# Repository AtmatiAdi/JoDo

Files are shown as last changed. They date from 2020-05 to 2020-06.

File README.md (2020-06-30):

# Opis projektu

Głównym celem projektu jest stworzenie Joystick'a na bazie mikrokontrolera STM32F103. Założeniem jest aby uniwersalnym urządzeniem można było sterować różnymi robotami przez moduł Bluetooth lub WIFI, oraz tradycyjnie obsługiwać komputer poprzez interfejs USB jako joystick lub jako mysz. Ma on posiadać niżej opisane funkcjonalności:

* Baterie do pracy bez zasilania przewodowego.
* Zintegrowaną ładowarkę i kontrolę napięcia baterii.
* Gałkę precyzyjną i  szereg przycisków do kontroli i sterowania.
* Akcelerometr do różnego rodzaju kontroli lub jako kolejna “gałka joysticka”.
* Interfejs USB umożliwiający podłączenie do komputera jako urządzenie HID jak i ładowanie samego urządzenia.
* Moduł Bluetooth, WIFI i radiowy umożliwiający implementację sterowania różnego rodzaju robotami.
 
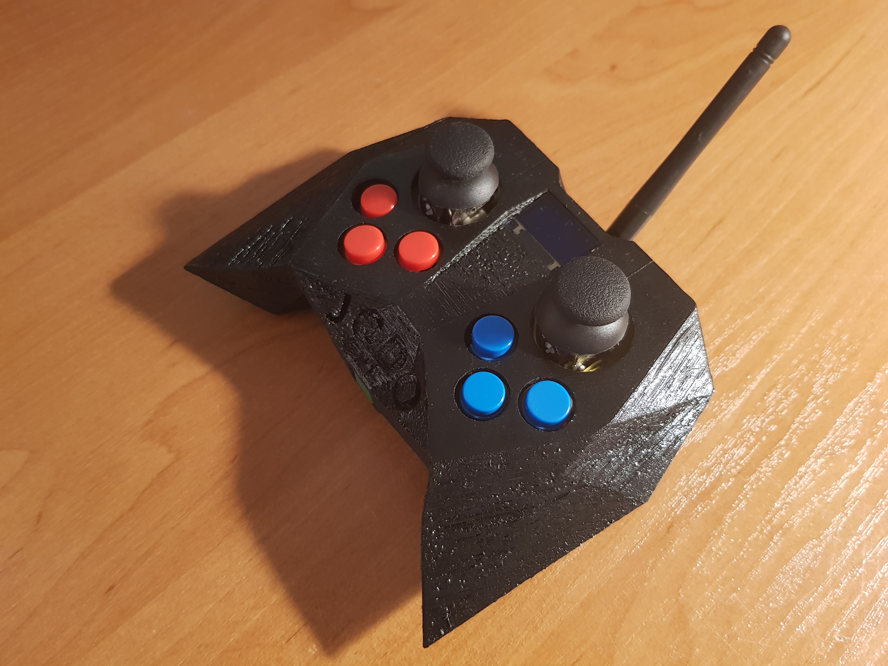
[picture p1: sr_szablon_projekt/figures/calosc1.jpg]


Mikrokontroler STM32F103 przez magistralę UART komunikować się będzie z modułem WIFI i modułem Bluetooth HC-05 aby umożliwić podłączenie i sterowanie innym urządzeniem. Moduł HC-05 jest programowalny (komendami AT można zmienić częstotliwość komunikacji i tryb pracy master/slave). Moduł komunikacji radiowej nRF24L01+ jest zasilany napięciem 1.9 - 3.6 V. Może pracować w trybie nadajnika i odbiornika. Wyświetlacz oled służy do wyświetlania informacji takich jak stan połączenia, informacje zwrotne z urządzenia, stan baterii itp. Przetwornica ma możliwość wyłączenia w przypadku rozładowania baterii, tym zarządza mikrokontroler. Głównym zadaniem będzie działanie jako joystick po podłączeniu do komputera przez USB. Moduł IMU służy jako kontroler tak jak sam joystick. Architektura systemu:

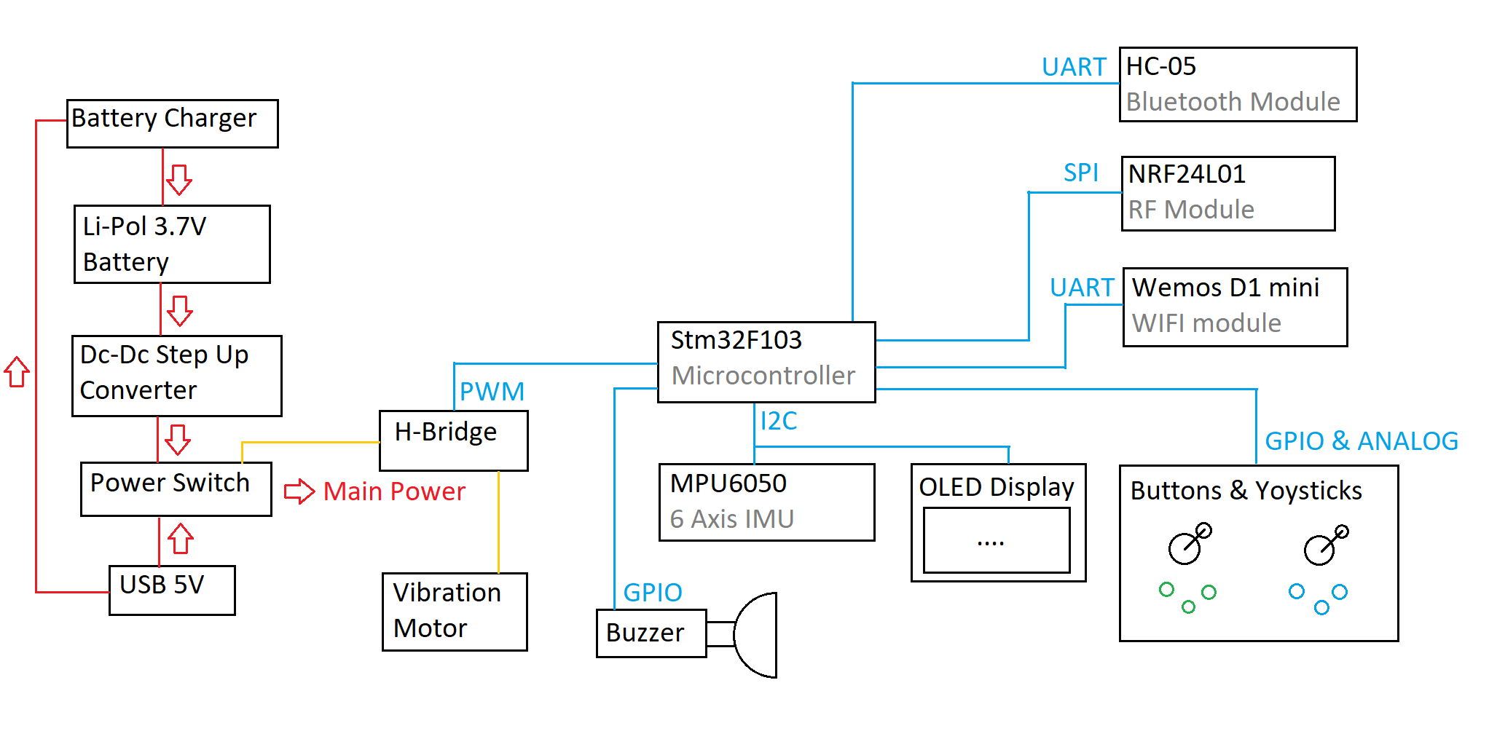
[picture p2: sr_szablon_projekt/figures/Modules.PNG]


# Opis działania programu

Uniwersalność urządzenia zapewniona jest poprzez możliwość wybierania trybów pracy. Tryb wybierany jest z menu  uruchamianego po włączeniu urządzenia. Do nawigacji po menu służą niebieskie przyciski - skrajne do zmiany opcji, a środkowy do zatwierdzenia. Podstawowym trybem jest praca jako gamepad, dodatkowo jednak na potrzeby projektu robota micromouse dodano tryb pracy jako mostek pomiędzy robotem a komputerem. W miarę potrzeb program można rozszerzyć o kolejne funkcje trybów z odpowiednio skonfigurowanymi peryferiami, w zależności od wymagań projektu. Program urządzenia podzielony jest na funkcje programów i na funkcje główne. Funkcje główne są odpowiedzialne za kontrolę urządzenia i inicjalizację modułów. Funkcje programów dzielą się na dwa typy: inicjalizacji i pętli, inicjalizacja wybranego programu sprowadza się do wywołania funkcji inicjalizujących moduły i~peryferia dostarczone przez funkcje główne, jest to umowny poziom abstrakcji. Funkcja petli programu jest rdzeniem programu, nie powinna ona byc nieskończoną pętlą, gdyz sama będzie wywoływana w takiej pętli, wraz z funkcją Update która odpowiedzialna jest za kontrolę baterii i zasilania. Program został zrealizowany w taki sposób, ponieważ nie można jednocześnie skonfigurować HID i interfejsu szeregowego, dalsze projekty mogły by powodowac inne konflikty. Wybór innego trybu pracy możliwy jest jedynie po zresetowaniu urządzenia.

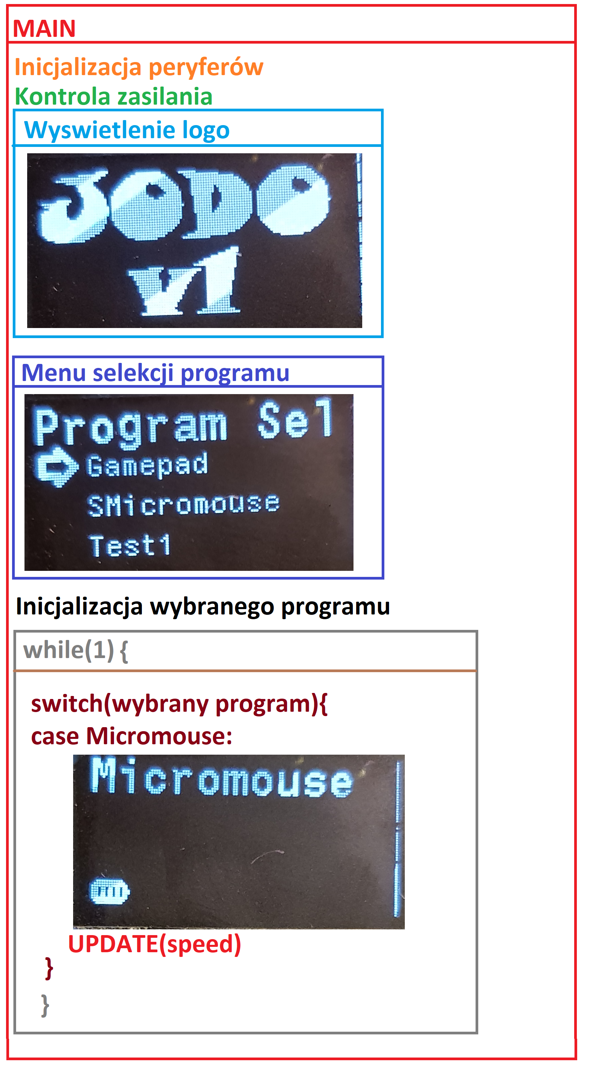
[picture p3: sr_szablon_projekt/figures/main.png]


# Linki 

https://youtu.be/tafsixhDsh8 - Prezentacja ukończenia projektu

https://www.overleaf.com/read/fwncyzqsmkhw - Raport końcowy

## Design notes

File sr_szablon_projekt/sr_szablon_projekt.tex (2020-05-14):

% !TeX encoding = UTF-8
% !TeX spellcheck = pl_PL

% $Id:$

%Author: Wojciech Domski
%Szablon do ząłożeń projektowych, raportu i dokumentacji z steorwników robotów
%Wersja v.1.0.0
%

%% Konfiguracja:
\newcommand{\kurs}{Sterowniki robot\'{o}w}
\newcommand{\formakursu}{Projekt}

%odkomentuj właściwy typ projektu, a pozostałe zostaw zakomentowane
\newcommand{\doctype}{Za\l{}o\.{z}enia projektowe} %etap I
%\newcommand{\doctype}{Raport} %etap II
%\newcommand{\doctype}{Dokumentacja} %etap III

%wpisz nazwę projektu
\newcommand{\projectname}{Joystick}

%wpisz akronim projektu
\newcommand{\acronim}{SteRoP\_2020\_J\_MKEZ\_1.pdf}

%wpisz Imię i nazwisko oraz numer albumu
\newcommand{\osobaA}{Mateusz \textsc{Kobak}, 241502}
%w przypadku projektu jednoosobowego usuń zawartość nowej komendy
\newcommand{\osobaB}{Ewa \textsc{Zi\k{e}tek}, 241479}

%wpisz termin w formie, jak poniżej dzień, parzystość, godzina
\newcommand{\termin}{ptTP11}

%wpisz imię i nazwisko prowadzącego
\newcommand{\prowadzacy}{dr in\.{z}. Wojciech \textsc{Domski}}

\documentclass[10pt, a4paper]{article}

\include{preambula}
	
\begin{document}

\def\tablename{Tabela}	%zmienienie nazwy tabel z Tablica na Tabela

\begin{titlepage}
	\begin{center}
		\textsc{\LARGE \formakursu}\\[1cm]		
		\textsc{\Large \kurs}\\[0.5cm]		
		\rule{\textwidth}{0.08cm}\\[0.4cm]
		{\huge \bfseries \doctype}\\[1cm]
		{\huge \bfseries \projectname}\\[0.5cm]
		{\huge \bfseries \acronim}\\[0.4cm]
		\rule{\textwidth}{0.08cm}\\[1cm]
		
		\begin{flushright} \large
		\emph{Skład grupy:}\\
		\osobaA\\
		\osobaB\\[0.4cm]
		
		\emph{Termin: }\termin\\[0.4cm]

		\emph{Prowadzący:} \\
		\prowadzacy \\
		
		\end{flushright}
		
		\vfill
		
		{\large \today}
	\end{center}	
\end{titlepage}

\newpage
\tableofcontents
\newpage

%Obecne we wszystkich dokumentach
\section{Opis projektu}
\label{sec:OpisProjektu}

Głównym celem projektu jest stworzenie Joystick na bazie mikrokontrolera STM32F103. Założeniem jest aby uniwersalnym urządzeniem można było sterować różnymi robotami przez interfejs Bluetooth lub WIFI. oraz tradycyjnie obsługiwać komputer poprzez interfejs USB jako joystick lub jako mysz, ma on posiadać niżej opisane funkcjonalności:
\begin{itemize}
	\item Baterie do pracy bez zasilania przewodowego.
	\item Zintegrowaną ładowarkę i kontrolę napięcia baterii.
	\item Gałkę precyzyjną i  szereg przycisków do kontroli i sterowania.
	\item Akcelerometr do różnego rodzaju kontroli czy będąc jako kolejna “gałka joysticka”.
	\item Interfejs USB umożliwiający podłączenie do komputera jako urządzenie HID jak i ładowanie samego urządzenia.
	\item Moduł Bluetooth i WIFI umożliwiający implementację sterowania różnego rodzaju robotami.
\end{itemize}
Krótki opis projektu czego będzie on dotyczył.

W przypadku, gdy projekt dotyczy systemu 
wielomodułowego należy dołączyć diagram, który będzie prezentował
architekturę systemu:

\begin{figure}[H]
	\centering
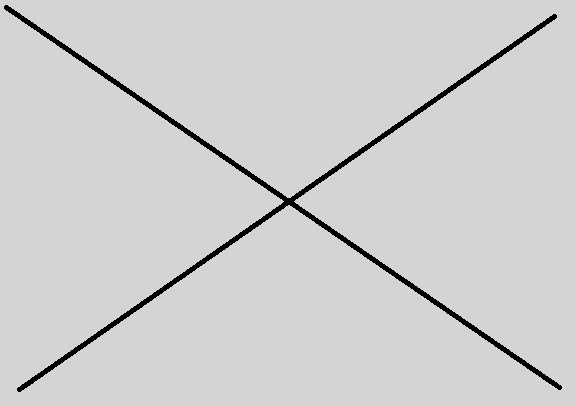
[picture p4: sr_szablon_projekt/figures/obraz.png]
	
	\caption{Architektura systemu}
	\label{fig:Architektura}
\end{figure}

%Obecne we wszystkich dokumentach
\section{Konfiguracja mikrokontrolera}

Tutaj powinna znaleźć się konfigurację poszczególnych peryferiów 
mikrokontrolera -- jeśli wykorzystywany jest np. ADC to należy 
podać jego konfigurację nie zapominając o DMA jeśli jest 
wykorzystywane. Proszę wzorować się na raporcie wygenerowanym 
z programu STM32CubeMx 
(plik PDF i TXT, Project -> Generate Report Ctrl+R). 
W pliku PDF jest to rozdział \textit{IPs} and \textit{Middleware Configuration}. 
Należy umieścić uproszczoną konfiguracje peryferiów w formie 
tabelek (najistotniejsze parametry + parametry zmienione, pogrubione).
Dodatkowo w pliku tekstowym (TXT) znajduje się konfiguracja pinów 
mikrokontrolera, którą również należy zamieścić w raporcie.

W przypadku, gdy projekt zakłada wykorzystanie większej liczby modułów
sekcję tą należy podzielić na odrębne podsekcje.

\begin{figure}[H]
	\centering
	
	\caption{Konfiguracja wyjść mikrokontrolera w programie STM32CubeMX}
	\label{fig:KonfiguracjaMikrokontrolera}
\end{figure}

\newpage
\begin{figure}[H]
	\centering
	
	\caption{Konfiguracja zegarów mikrokontrolera}
	\label{fig:KonfiguracjaZegara}
\end{figure}

%Obecne we wszystkich dokumentach
\subsection{Konfiguracja pinów}

\begin{table}[H]
	\centering
	\begin{tabular}{|l|l|l|l|}
		\hline
		Numer pinu	&	PIN & Tryb pracy & Funkcja/etykieta\\
		\hline
		2&	PC13 & ANTI\_TAMP	GPIO\_EXTI13	&B1 [Blue PushButton]\\
		3&	PC14 & OSC32\_IN*	RCC\_OSC32\_IN	&\\
		4&	PC15 & OSC32\_OUT*	RCC\_OSC32\_OUT	&\\
		5&	PH0&  OSC\_IN*	RCC\_OSC\_IN	&\\
		6&	PH1&  OSC\_OUT*&		RCC\_OSC\_OUT	\\
		16&	PA2&	USART2\_TX&	USART\_TX\\
		17&	PA3&	USART2\_RX&	USART\_RX\\
		21&	PA5&	GPIO\_Output&	LD2 [Green Led]\\
		29&	PB10&	I2C2\_SCL&	I2C\_SCL\\
		41&	PA8&	TIM1\_CH1&	PWM1\\
		46&	PA13*&	SYS\_JTMS-SWDIO&	TMS\\
		49&	PA14*&	SYS\_JTCK-SWCLK&	TCK\\
		55&	PB3*&	SYS\_JTDO-SWO&	SWO\\
		62&	PB9&	I2C2\_SDA&	I2C\_SCL\\
		\hline
	\end{tabular}
	\caption{Konfiguracja pinów mikrokontrolera}
	
\end{table}

%Obecne we wszystkich dokumentach
\subsection{USART}

Przykładowa konfiguracja peryferium interfejsu szeregowego.
Należy opisać do czego będzie wykorzystywany interfejs. 
Zmiany, które odbiegają od standardowych w programie CubeMX 
powinn być zaznaczone innym kolorem, jak to zostało pokazane 
w tabeli \ref{tab:USART}.

\begin{table}[H]
	\centering
	\begin{tabular}{|l|c|} \hline
		\textbf{Parametr} & Wartość \\
		\hline
		\hline  \textbf{Baud Rate}&11520  \\\hline
		\textbf{Word Length } & \textcolor{blue}{8 Bits (including parity)}\\\hline
		\textbf{Parity} &  None\\
		\hline
		\textbf{Stop Bits}& 1\\
		\hline
	\end{tabular}
	\caption{Konfiguracja peryferium USART}
	\label{tab:USART}
\end{table}

%Obecne w dokumencie do etapu II oraz III
%\section{Urządzenia zewnętrzne}

%Rozdział ten powinien zawierać opis i konfigurację wykorzystanych ukladów
%zewnętrznych, jak np. akcelerometr.

%Obecne w dokumencie do etapu II oraz III
%\subsection{Akcelerometr -- LSM303C}

%Akcelerometr został wykorzystany do ...

%Konfiguracja rejestrów czujnika została zaprezentowana w ...
%Wpisanie tych wartości do rejestrów urządzenia ... powoduje ...

%\begin{table}[H]
%	\centering
%	\begin{tabular}{|l|c|} \hline
%		\textbf{Rejestr} & Wartość \\
%		\hline
%		\hline
%		CTRL\_REG2 (0x21) & 0x12\\\hline
%		CTRL\_REG3 (0x22) & 0x13\\\hline
%	\end{tabular}
%	\caption{Konfiguracja peryferium USART}
%	\label{tab:Akcelerometr}
%\end{table}

%Obecne w dokumencie do etapu II oraz III
%\section{Projekt elektroniki}

%W przypadku, w którym projekt uwzględnia zastosowanie 
%dodatkowej elektroniki to wówczas jej opis powinien znaleźć się tutaj.
%Należy dołączyć schematy elektroniczne w formacie PDF 
%jako dodatek do dokumentu 
%za pomocą \textit{include}. Również w przypadku wytworzenia 
%płytek PCB powinny znaleźć się tutaj ich widoki za zachowaniem skali.
%Można również dołączyć zdjęcia 
%elektroniki po uprzednim skompresowaniu, aby wynikowy rozmiar 
%skompilowanego dokumentu nie był za duży.

%Obecne w dokumencie do etapu II oraz III
%\section{Konstrukcja mechaniczna}

%W przypadku, w którym projekt uwzględnia zastosowanie 
%mechaniki to wówczas jej opis powinien znaleźć się tutaj.
%Nie należy dzielić rysunków mechaniki na poszczególne rzuty, 
%wystarczy zamieścić wyrenderowane modele 3D.
%Można również dołączyć zdjęcia wykonanej 
%mechaniki po uprzednim skompresowaniu, aby wynikowy rozmiar 
%skompilowanego dokumentu nie był za duży.

%Obecne w dokumencie do etapu II oraz III
%\section{Opis działania programu}

%Należy zawrzeć tutaj opis działania programu.
%Mile widziany diagram prezentujący pracę programu.

%\begin{figure}[H]
%	\centering
%	\includegraphics[width=0.5\textwidth]{figures/obraz.png}
%	\caption{Diagram przepływu}
%	\label{fig:Program}
%\end{figure}

%Sekcję tą można podzielić na dodatkowe podsekcje w miarę potrzeb. 
%Do tego celu nalezy wykorzystać \textit{subsection}.

%W przypadku, dodania istotnego fragmentu kodu należy posłużyć się środowiskiem 
%lstlisting:

%\begin{lstlisting}[tabsize=2]
%int foo(void){
%return 2;
%}
%\end{lstlisting}

%Przykładowy wzór (\ref{eq:Wzor}):
%\begin{equation}
%\label{eq:Wzor}
%\Theta = \int_t^{t+dt} \omega \, dt.	
%\end{equation}

%Przykładowa pozycja bibliograficzna \cite{SR01} znajduje się 
%w pliku bibliografia.bib.

%Obecne w dokumencie do etapu I
\section{Harmonogram pracy}

Należy wstawić diagram Gantta oraz określić ścieżkę 
krytyczną. Ponadto zaznaczyć i opisać kamienie milowe.

\begin{figure}[H]
	\centering
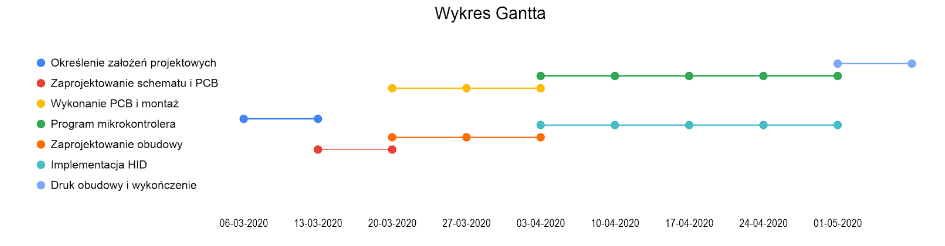
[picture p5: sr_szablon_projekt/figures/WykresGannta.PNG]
	
	\caption{Diagram Gantta}
	\label{fig:DiagramGantta}
\end{figure}

%Obecne w dokumencie do etapu I
\subsection{Podział pracy}

%\textbf{Każdy z członków grupy powinien w każdym etapie mieć wymienione od 2 do 4 zadań.}
%Przykładowa tabele podziału zadań dla etapu II 
%(Tab. \ref{tab:PodzialPracyEtap2}) oraz dla etapu III 
%(Tab. \ref{tab:PodzialPracyEtap3})
%zostały przedstawione poniżej. 
%Przy podziale prac nie uwzględniamy tworzenia dokumentacji projektu!

%Przykładowy podział prac dla projektu pod tytułem 
%"Automatyczny dyktafon rozmowy":

\begin{table}[H]
	\centering
	\begin{tabular}{|L{7cm}|L{0.8cm}||L{7cm}|L{0.8cm}|}
		\hline
		\hline
		\textbf{Mateusz Kobak} & 
		\% & 
		\textbf{Ewa Ziętek} & \%\\
		\hline
		\hline
			Dobranie odpowiednich komponentów	& &	
	 Dobranie odpowiednich komponentów &\\
		\hline
		Zaprojektowanie schematu i PCB & &
 &\\
		\hline
			 & &
		Wykonanie PCB i montaż & \\
		\hline
%		 & & &\\
%		\hline
	\end{tabular}
	\caption{Podział pracy -- Etap II}
	\label{tab:PodzialPracyEtap2}
\end{table}

\begin{table}[H]
	\centering
	\begin{tabular}{|L{7cm}|L{0.8cm}||L{7cm}|L{0.8cm}|}
		\hline
		\hline
		\textbf{Mateusz Kobak} & 
		\% & 
		\textbf{Ewa Ziętek} & \%\\
		\hline
		\hline
	Zaprojektowanie obudowy		& &	
		Program mikrokontrolera &\\
		\hline
	Implementacja HID  & &
		Druk obudowy i wykończenie &\\
		\hline

	\end{tabular}
	\caption{Podział pracy -- Etap III}
	\label{tab:PodzialPracyEtap3}
\end{table}

%Obecne w dokumencie do etapu II oraz III (jeśli coś zostało niezrealizowane)
%\section{Zadania niezrealizowane}

%Jeśli wszystkie zadania zostały realizowane to wówczas 
%ta sekcja powinna być usunięta w całości. W przeciwnym razie
%należy zawrzeć tutaj, jakie zadania zostały nie zrealizowane 
%oraz jaka była tego przyczyna.

%Obecne we wszystkich dokumentach
\section{Podsumowanie}

Urządzenie jest modułowe, więc ewentualna wymiana uszkodzonych elementów będzie łatwa. Drukowaną obudowę można łatwo powielić i wymienić. Budowa Joystick'a jest niedroga, tanim kosztem można zbudować ich więcej.

\newpage
\addcontentsline{toc}{section}{Bibilografia}
\bibliography{bibliografia}
\bibliographystyle{plabbrv}

\end{document}

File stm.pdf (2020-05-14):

## stm Project Configuration Report

# 1. Description

## 1.1. Project

Project Name | stm
Board Name | No information
Generated with: | STM32CubeMX 4.24.0
Date | 03/05/2020

## 1.2. MCU

MCU Series | STM32F1
MCU Line | STM32F103
MCU name | STM32F103CBTx
MCU Package | LQFP48
MCU Pin number | 48

# 2. Pinout Configuration

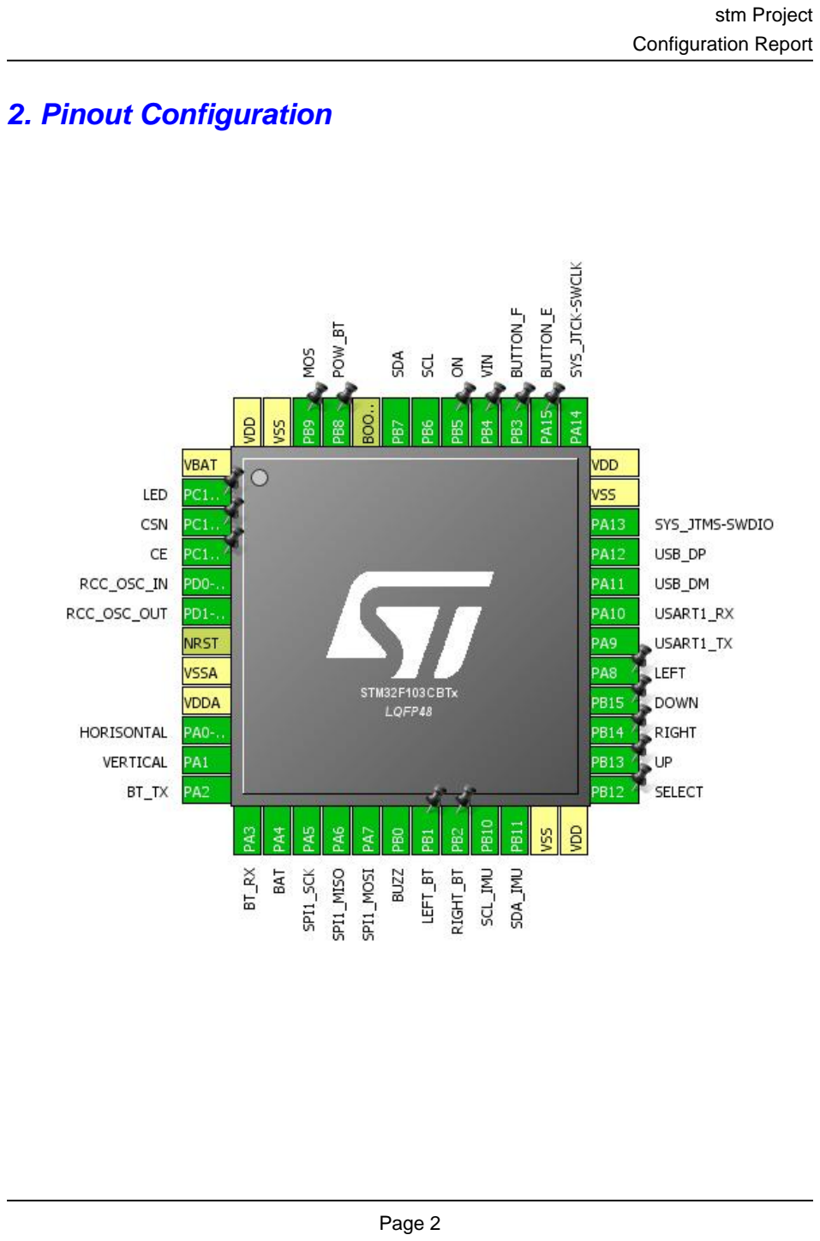
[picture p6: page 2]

# 3. Pins Configuration

Pin Number LQFP48 | Pin Name (function after reset) | Pin Type | Alternate Function(s) | Label
1 | VBAT | Power
2 | PC13-TAMPER-RTC * | I/O | GPIO_Output | LED
3 | PC14-OSC32_IN * | I/O | GPIO_Output | CSN
4 | PC15-OSC32_OUT * | I/O | GPIO_Output | CE
5 | PD0-OSC_IN | I/O | RCC_OSC_IN
6 | PD1-OSC_OUT | I/O | RCC_OSC_OUT
7 | NRST | Reset
8 | VSSA | Power
9 | VDDA | Power
10 | PA0-WKUP | I/O | ADC1_IN0 | HORISONTAL
11 | PA1 | I/O | ADC1_IN1 | VERTICAL
12 | PA2 | I/O | USART2_TX | BT_TX
13 | PA3 | I/O | USART2_RX | BT_RX
14 | PA4 | I/O | ADC1_IN4 | BAT
15 | PA5 | I/O | SPI1_SCK
16 | PA6 | I/O | SPI1_MISO
17 | PA7 | I/O | SPI1_MOSI
18 | PB0 | I/O | TIM3_CH3 | BUZZ
19 | PB1 * | I/O | GPIO_Input | LEFT_BT
20 | PB2 * | I/O | GPIO_Input | RIGHT_BT
21 | PB10 | I/O | I2C2_SCL | SCL_IMU
22 | PB11 | I/O | I2C2_SDA | SDA_IMU
23 | VSS | Power
24 | VDD | Power
25 | PB12 * | I/O | GPIO_Input | SELECT
26 | PB13 * | I/O | GPIO_Input | UP
27 | PB14 * | I/O | GPIO_Input | RIGHT
28 | PB15 * | I/O | GPIO_Input | DOWN
29 | PA8 * | I/O | GPIO_Input | LEFT
30 | PA9 | I/O | USART1_TX
31 | PA10 | I/O | USART1_RX
32 | PA11 | I/O | USB_DM
33 | PA12 | I/O | USB_DP
34 | PA13 | I/O | SYS_JTMS-SWDIO
35 | VSS | Power
36 | VDD | Power

Pin Number LQFP48 | Pin Name (function after reset) | Pin Type | Alternate Function(s) | Label
37 | PA14 | I/O | SYS_JTCK-SWCLK
38 | PA15 * | I/O | GPIO_Input | BUTTON_E
39 | PB3 * | I/O | GPIO_Input | BUTTON_F
40 | PB4 * | I/O | GPIO_Input | VIN
41 | PB5 * | I/O | GPIO_Output | ON
42 | PB6 | I/O | I2C1_SCL | SCL
43 | PB7 | I/O | I2C1_SDA | SDA
44 | BOOT0 | Boot
45 | PB8 * | I/O | GPIO_Input | POW_BT
46 | PB9 * | I/O | GPIO_Output | MOS
47 | VSS | Power
48 | VDD | Power

## * The pin is affected with an I/O function

# 4. Clock Tree Configuration

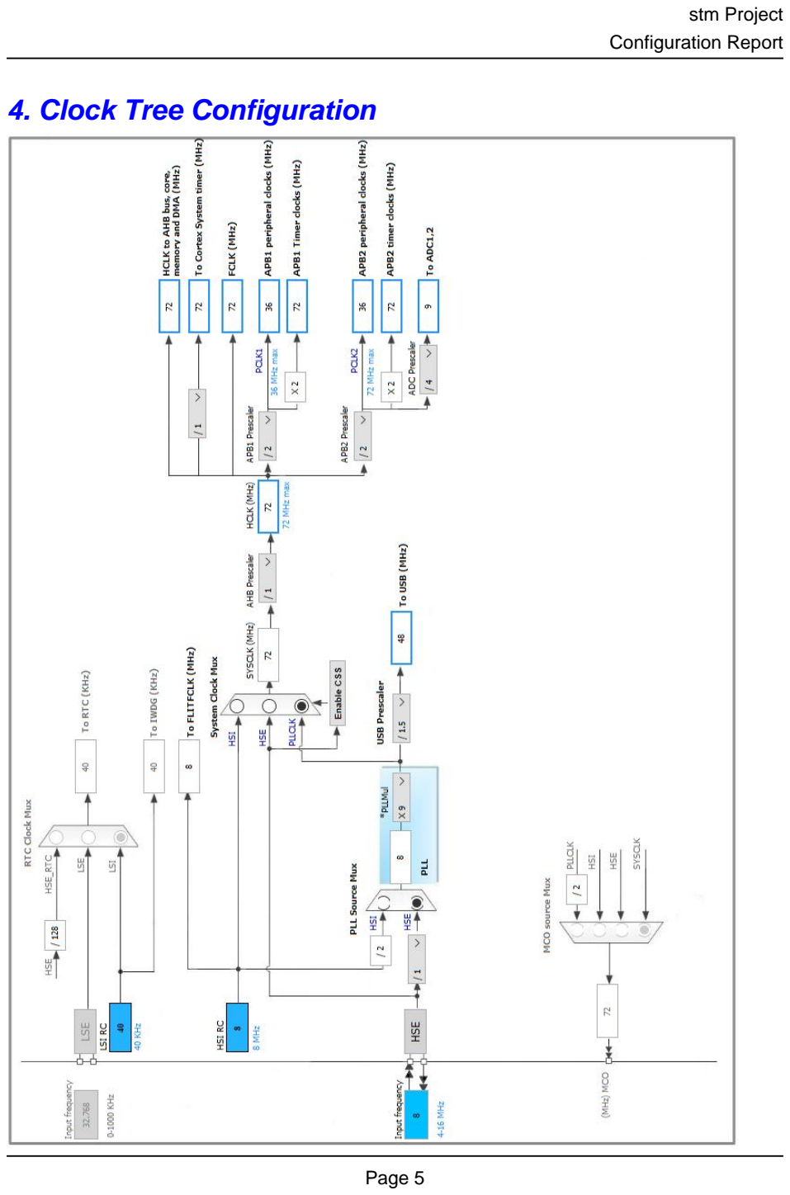
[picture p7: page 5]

# 5. IPs and Middleware Configuration

# 5.1. ADC1

## mode: IN0 mode: IN1 mode: IN4

## 5.1.1. Parameter Settings:

### ADCs_Common_Settings:

Mode | Independent mode

### ADC_Settings:

Data Alignment | Right alignment
Scan Conversion Mode | Disabled
Continuous Conversion Mode | Disabled
Discontinuous Conversion Mode | Disabled

### ADC_Regular_ConversionMode:

Enable Regular Conversions | Enable
Number Of Conversion | 1
External Trigger Conversion Source | Regular Conversion launched by software
Rank | 1
Channel | Channel 0
Sampling Time | 1.5 Cycles

### ADC_Injected_ConversionMode:

Number Of Conversions | 0

### WatchDog:

Enable Analog WatchDog Mode | false

# 5.2. I2C1

## I2C: I2C

## 5.2.1. Parameter Settings:

### Master Features:

I2C Speed Mode | Standard Mode
I2C Clock Speed (Hz) | 100000

### Slave Features:

Clock No Stretch Mode | Disabled
Primary Address Length selection | 7-bit
Dual Address Acknowledged | Disabled
Primary slave address | 0
General Call address detection | Disabled

# 5.3. I2C2

## I2C: I2C

## 5.3.1. Parameter Settings:

### Master Features:

I2C Speed Mode | Standard Mode
I2C Clock Speed (Hz) | 100000

### Slave Features:

Clock No Stretch Mode | Disabled
Primary Address Length selection | 7-bit
Dual Address Acknowledged | Disabled
Primary slave address | 0
General Call address detection | Disabled

# 5.4. RCC

## High Speed Clock (HSE): Crystal/Ceramic Resonator

## 5.4.1. Parameter Settings:

### System Parameters:

VDD voltage (V) | 3.3
Prefetch Buffer | Enabled
Flash Latency(WS) | 2 WS (3 CPU cycle)

### RCC Parameters:

HSI Calibration Value | 16
HSE Startup Timout Value (ms) | 100
LSE Startup Timout Value (ms) | 5000

# 5.5. SPI1

## Mode: Full-Duplex Master

## 5.5.1. Parameter Settings:

### Basic Parameters:

Frame Format | Motorola
Data Size | 8 Bits
First Bit | MSB First

### Clock Parameters:

Prescaler (for Baud Rate) | 2
Baud Rate | 18.0 MBits/s *
Clock Polarity (CPOL) | Low
Clock Phase (CPHA) | 1 Edge

### Advanced Parameters:

CRC Calculation | Disabled
NSS Signal Type | Software

# 5.6. SYS

## Debug: Serial Wire Timebase Source: SysTick

# 5.7. TIM3

## Channel3: PWM Generation CH3

## 5.7.1. Parameter Settings:

### Counter Settings:

Prescaler (PSC - 16 bits value) | 0
Counter Mode | Up
Counter Period (AutoReload Register - 16 bits value ) | 0
Internal Clock Division (CKD) | No Division
auto-reload preload | Disable

### Trigger Output (TRGO) Parameters:

Master/Slave Mode (MSM bit) | Disable (Trigger input effect not delayed)

Trigger Event Selection | Reset (UG bit from TIMx_EGR)

### PWM Generation Channel 3:

Mode | PWM mode 1
Pulse (16 bits value) | 0
Fast Mode | Disable
CH Polarity | High

# 5.8. USART1

## Mode: Asynchronous

## 5.8.1. Parameter Settings:

### Basic Parameters:

Baud Rate | 115200
Word Length | 8 Bits (including Parity)
Parity | None
Stop Bits | 1

### Advanced Parameters:

Data Direction | Receive and Transmit
Over Sampling | 16 Samples

# 5.9. USART2

## Mode: Asynchronous

## 5.9.1. Parameter Settings:

### Basic Parameters:

Baud Rate | 115200
Word Length | 8 Bits (including Parity)
Parity | None
Stop Bits | 1

### Advanced Parameters:

Data Direction | Receive and Transmit
Over Sampling | 16 Samples

# 5.10. USB

## mode: Device (FS)

## 5.10.1. Parameter Settings:

### Basic Parameters:

Speed | Full Speed 12MBit/s
Endpoint 0 Max Packet size | 8 Bytes

### Power Parameters:

Low Power | Disabled
Link Power Management | Disabled
Battery Charging | Disabled

# 5.11. USB_DEVICE

## Class For FS IP: Human Interface Device Class (HID)

## 5.11.1. Parameter Settings:

### Basic Parameters:

USBD_MAX_NUM_INTERFACES (Maximum number of supported interfaces) | 1
USBD_MAX_NUM_CONFIGURATION (Maximum number of supported configuration) | 1
USBD_MAX_STR_DESC_SIZ (Maximum size for the string descriptors) | 512
USBD_SUPPORT_USER_STRING (Enable user string descriptor) | Disabled
USBD_SELF_POWERED (Enabled self power) | Enabled
USBD_DEBUG_LEVEL (USBD Debug Level) | 0: No debug message

## 5.11.2. Device Descriptor:

### Device Descriptor:

VID (Vendor IDentifier) | 1155
LANGID_STRING (Language Identifier) | English(United States)
MANUFACTURER_STRING (Manufacturer Identifier) | STMicroelectronics

### Device Descriptor FS:

PID (Product IDentifier) | 22315
PRODUCT_STRING (Product Identifier) | STM32 Human interface
SERIALNUMBER_STRING (Serial number) | 00000000001A

CONFIGURATION_STRING (Configuration Identifier) | HID Config
INTERFACE_STRING (Interface Identifier) | HID Interface

### * User modified value

# 6. System Configuration

# 6.1. GPIO configuration

IP | Pin | Signal | GPIO mode | GPIO pull/up pull down

## Max Speed

## User Label

ADC1 | PA0-WKUP | ADC1_IN0 | Analog mode | n/a | n/a | HORISONTAL
| PA1 | ADC1_IN1 | Analog mode | n/a | n/a | VERTICAL
| PA4 | ADC1_IN4 | Analog mode | n/a | n/a | BAT
I2C1 | PB6 | I2C1_SCL | Alternate Function Open Drain | n/a | High * | SCL
| PB7 | I2C1_SDA | Alternate Function Open Drain | n/a | High * | SDA
I2C2 | PB10 | I2C2_SCL | Alternate Function Open Drain | n/a | High * | SCL_IMU
| PB11 | I2C2_SDA | Alternate Function Open Drain | n/a | High * | SDA_IMU
RCC | PD0- OSC_IN | RCC_OSC_IN | n/a | n/a | n/a
| PD1- OSC_OUT | RCC_OSC_OUT | n/a | n/a | n/a
SPI1 | PA5 | SPI1_SCK | Alternate Function Push Pull | n/a | High *
| PA6 | SPI1_MISO | Input mode | No pull-up and no pull-down | n/a
| PA7 | SPI1_MOSI | Alternate Function Push Pull | n/a | High *
SYS | PA13 | SYS_JTMS- SWDIO | n/a | n/a | n/a
| PA14 | SYS_JTCK- SWCLK | n/a | n/a | n/a
TIM3 | PB0 | TIM3_CH3 | Alternate Function Push Pull | n/a | Low | BUZZ
USART1 | PA9 | USART1_TX | Alternate Function Push Pull | n/a | High *
| PA10 | USART1_RX | Input mode | No pull-up and no pull-down | n/a
USART2 | PA2 | USART2_TX | Alternate Function Push Pull | n/a | High * | BT_TX
| PA3 | USART2_RX | Input mode | No pull-up and no pull-down | n/a | BT_RX
USB | PA11 | USB_DM | n/a | n/a | n/a
| PA12 | USB_DP | n/a | n/a | n/a
GPIO | PC13- TAMPER- RTC | GPIO_Output | Output Push Pull | n/a | Low | LED

PC14-
OSC32_IN
| GPIO_Output | Output Push Pull | n/a | Low | CSN
PC15- | GPIO_Output | Output Push Pull | n/a | Low | CE

IP | Pin | Signal | GPIO mode | GPIO pull/up pull down | Max Speed | User Label
| OSC32_OU T
| PB1 | GPIO_Input | Input mode | No pull-up and no pull-down | n/a | LEFT_BT
| PB2 | GPIO_Input | Input mode | No pull-up and no pull-down | n/a | RIGHT_BT
| PB12 | GPIO_Input | Input mode | No pull-up and no pull-down | n/a | SELECT
| PB13 | GPIO_Input | Input mode | No pull-up and no pull-down | n/a | UP
| PB14 | GPIO_Input | Input mode | No pull-up and no pull-down | n/a | RIGHT
| PB15 | GPIO_Input | Input mode | No pull-up and no pull-down | n/a | DOWN
| PA8 | GPIO_Input | Input mode | No pull-up and no pull-down | n/a | LEFT
| PA15 | GPIO_Input | Input mode | No pull-up and no pull-down | n/a | BUTTON_E
| PB3 | GPIO_Input | Input mode | No pull-up and no pull-down | n/a | BUTTON_F
| PB4 | GPIO_Input | Input mode | No pull-up and no pull-down | n/a | VIN
| PB5 | GPIO_Output | Output Push Pull | n/a | Low | ON
| PB8 | GPIO_Input | Input mode | No pull-up and no pull-down | n/a | POW_BT
| PB9 | GPIO_Output | Output Push Pull | n/a | Low | MOS

# 6.2. DMA configuration

## nothing configured in DMA service

# 6.3. NVIC configuration

Interrupt Table | Enable | Preenmption Priority | SubPriority
Non maskable interrupt | true | 0 | 0
Hard fault interrupt | true | 0 | 0
Memory management fault | true | 0 | 0
Prefetch fault, memory access fault | true | 0 | 0
Undefined instruction or illegal state | true | 0 | 0
System service call via SWI instruction | true | 0 | 0
Debug monitor | true | 0 | 0
Pendable request for system service | true | 0 | 0
System tick timer | true | 0 | 0
USB low priority or CAN RX0 interrupts | true | 0 | 0
PVD interrupt through EXTI line 16 | unused
Flash global interrupt | unused
RCC global interrupt | unused
ADC1 and ADC2 global interrupts | unused
USB high priority or CAN TX interrupts | unused
TIM3 global interrupt | unused
I2C1 event interrupt | unused
I2C1 error interrupt | unused
I2C2 event interrupt | unused
I2C2 error interrupt | unused
SPI1 global interrupt | unused
USART1 global interrupt | unused
USART2 global interrupt | unused

### * User modified value

# 7. Power Consumption Calculator report

### 7.1. Microcontroller Selection

Series | STM32F1
Line | STM32F103
MCU | STM32F103CBTx
Datasheet | 13587_Rev17

### 7.2. Parameter Selection

Temperature | 25
Vdd | 3.3

# 8. Software Pack Report

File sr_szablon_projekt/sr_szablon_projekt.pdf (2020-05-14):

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

## 1 Opis projektu

Gªównym celem projektu jest stworzenie Joystick na bazie mikrokontrolera STM32F103. Zaªo»eniem jest aby uniwersalnym urz¡dzeniem mo»na byªo sterowa¢ ró»nymi robotami przez interfejs Bluetooth lub WIFI. oraz tradycyjnie obsªugiwa¢ komputer poprzez interfejs USB jako joystick lub jako mysz, ma on posiada¢ ni»ej opisane funkcjonalno±ci:

| Baterie do pracy bez zasilania przewodowego.
| Zintegrowan¡ ªadowark¦ i kontrol¦ napi¦cia baterii.
| Gaªk¦ precyzyjn¡ i szereg przycisków do kontroli i sterowania.
| Akcelerometr do ró»nego rodzaju kontroli czy b¦d¡c jako kolejna gaªka joysticka.
| Interfejs USB umo»liwiaj¡cy podª¡czenie do komputera jako urz¡dzenie HID jak i ªadowanie samego urz¡dzenia.
| Moduª Bluetooth i WIFI umo»liwiaj¡cy implementacj¦ sterowania ró»nego rodzaju robotami.

Krótki opis projektu czego b¦dzie on dotyczyª.
W przypadku, gdy projekt dotyczy systemu wielomoduªowego nale»y doª¡czy¢ diagram, który b¦dzie prezentowaª architektur¦ systemu:


Rysunek 1: Architektura systemu

2 Konguracja mikrokontrolera Tutaj powinna znale¹¢ si¦ konguracj¦ poszczególnych peryferiów mikrokontrolera je±li wykorzysty-

wany jest np. ADC to nale»y poda¢ jego konguracj¦ nie zapominaj¡c o DMA je±li jest wykorzystywane. Prosz¦ wzorowa¢ si¦ na raporcie wygenerowanym z programu STM32CubeMx (plik PDF i TXT, Project -> Generate Report Ctrl+R). W pliku PDF jest to rozdziaª IPs and Middleware Conguration. Nale»y umie±ci¢ uproszczon¡ konguracje peryferiów w formie tabelek (najistotniejsze parametry + parametry zmienione, pogrubione). Dodatkowo w pliku tekstowym (TXT) znajduje si¦ konguracja pinów mikrokontrolera, któr¡ równie» nale»y zamie±ci¢ w raporcie.
| W przypadku, gdy projekt zakªada wykorzystanie wi¦kszej liczby moduªów sekcj¦ t¡ nale»y podzieli¢
na odr¦bne podsekcje.

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

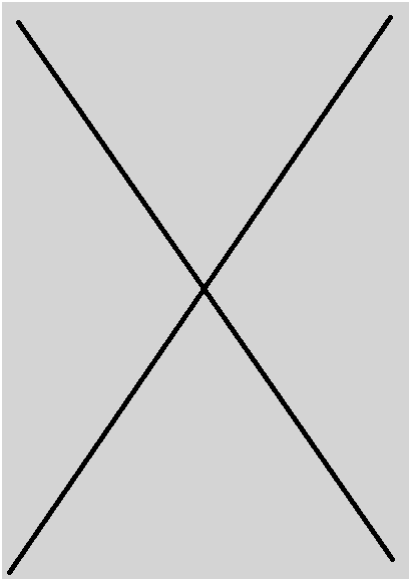
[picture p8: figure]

2.1 | Konguracja pinów
Numer pinu | PIN | Tryb pracy | Funkcja/etykieta
2 3 4 5 6 16 17 21 29 41 46 49 55 62 | PC13 PC14 PC15 PH0 PH1 PA2 PA3 PA5 PB10 PA8 PA13* PA14* PB3* PB9 | ANTI_TAMP GPIO_EXTI13 OSC32_IN* RCC_OSC32_IN OSC32_OUT* RCC_OSC32_OUT OSC_IN* RCC_OSC_IN OSC_OUT* USART2_TX USART2_RX GPIO_Output I2C2_SCL TIM1_CH1 SYS_JTMS-SWDIO SYS_JTCK-SWCLK SYS_JTDO-SWO I2C2_SDA | B1 [Blue PushButton] RCC_OSC_OUT USART_TX USART_RX LD2 [Green Led] I2C_SCL PWM1 TMS TCK SWO I2C_SCL

Tabela 1: Konguracja pinów mikrokontrolera

2.2 USART

Przykªadowa konguracja peryferium interfejsu szeregowego. Nale»y opisa¢ do czego b¦dzie wykorzystywany interfejs. Zmiany, które odbiegaj¡ od standardowych w programie CubeMX powinn by¢ zaznaczone innym kolorem, jak to zostaªo pokazane w tabeli 2.

Parametr | Warto±¢
Baud Rate | 11520
Word Length | 8 Bits (including parity)
Parity | None
Stop Bits | 1

Tabela 2: Konguracja peryferium USART

3 | Harmonogram pracy
| Nale»y wstawi¢ diagram Gantta oraz okre±li¢ ±cie»k¦ krytyczn¡. Ponadto zaznaczy¢ i opisa¢ kamienie
milowe.

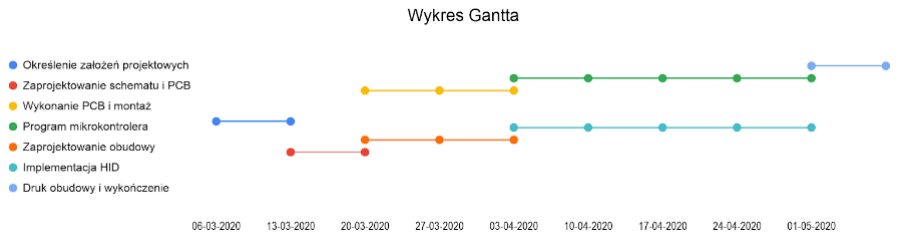
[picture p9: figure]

Rysunek 4: Diagram Gantta

3.1 | Podziaª pracy
Mateusz Kobak | % | Ewa Zi¦tek | %
Dobranie odpowiednich komponentów | | Dobranie odpowiednich komponentów
Zaprojektowanie schematu i PCB
| | Wykonanie PCB i monta»

Tabela 3: Podziaª pracy Etap II

Mateusz Kobak | % | Ewa Zi¦tek | %
Zaprojektowanie obudowy | | Program mikrokontrolera
Implementacja HID | | Druk obudowy i wyko«czenie

Tabela 4: Podziaª pracy Etap III

4 | Podsumowanie
| Urz¡dzenie jest moduªowe, wi¦c ewentualna wymiana uszkodzonych elementów b¦dzie ªatwa. Druko-
wan¡ obudow¦ mo»na ªatwo powieli¢ i wymieni¢. Budowa Joystick'a jest niedroga, tanim kosztem mo»na zbudowa¢ ich wi¦cej.

## Literatura

[1] W. Domski. Sterowniki robotów, Laboratorium Wprowadzenie, Wykorzystanie narz¦dzi STM32CubeMX oraz SW4STM32 do budowy programu mrugaj¡cej diody z obsªug¡ przycisku. Mar. 2017.
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

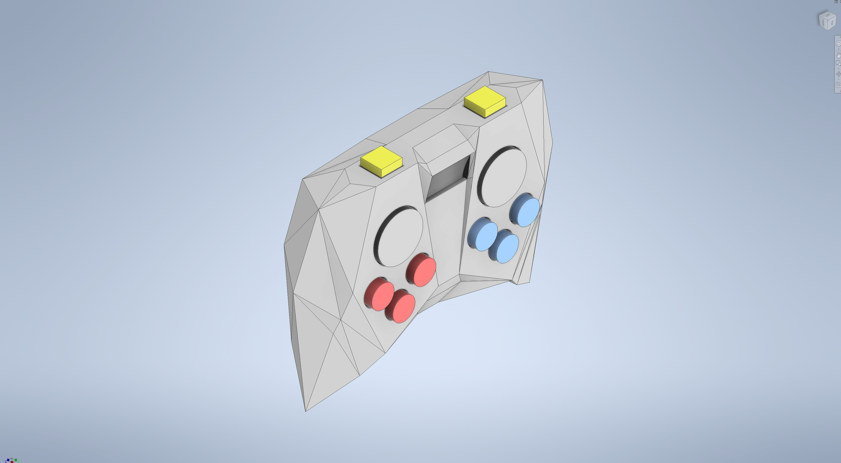
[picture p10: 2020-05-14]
sr_szablon_projekt/figures/obudowa_2.PNG

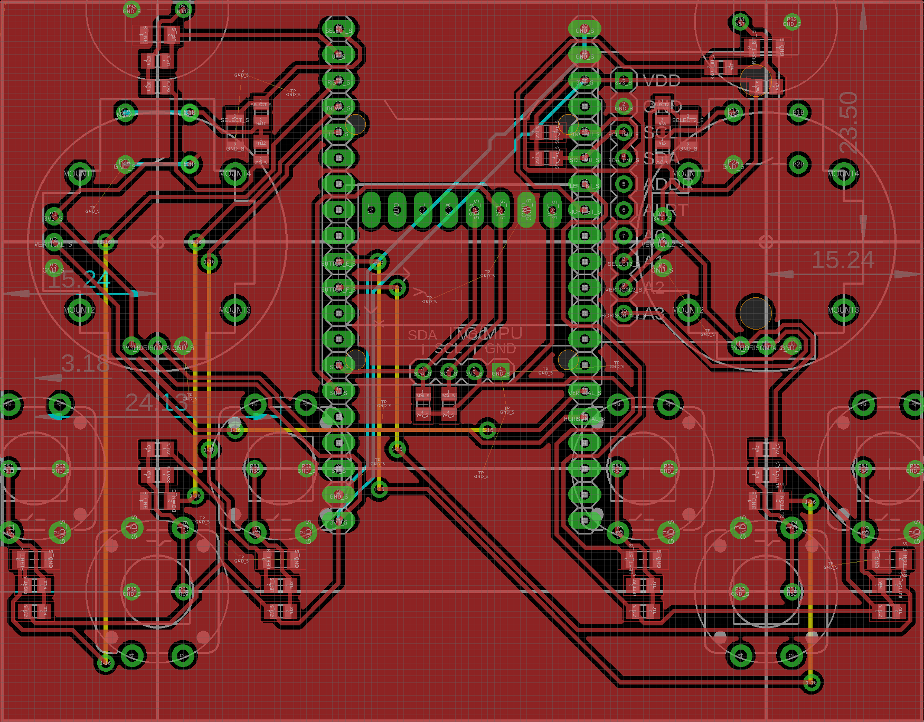
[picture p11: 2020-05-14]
sr_szablon_projekt/figures/pcb_top.PNG

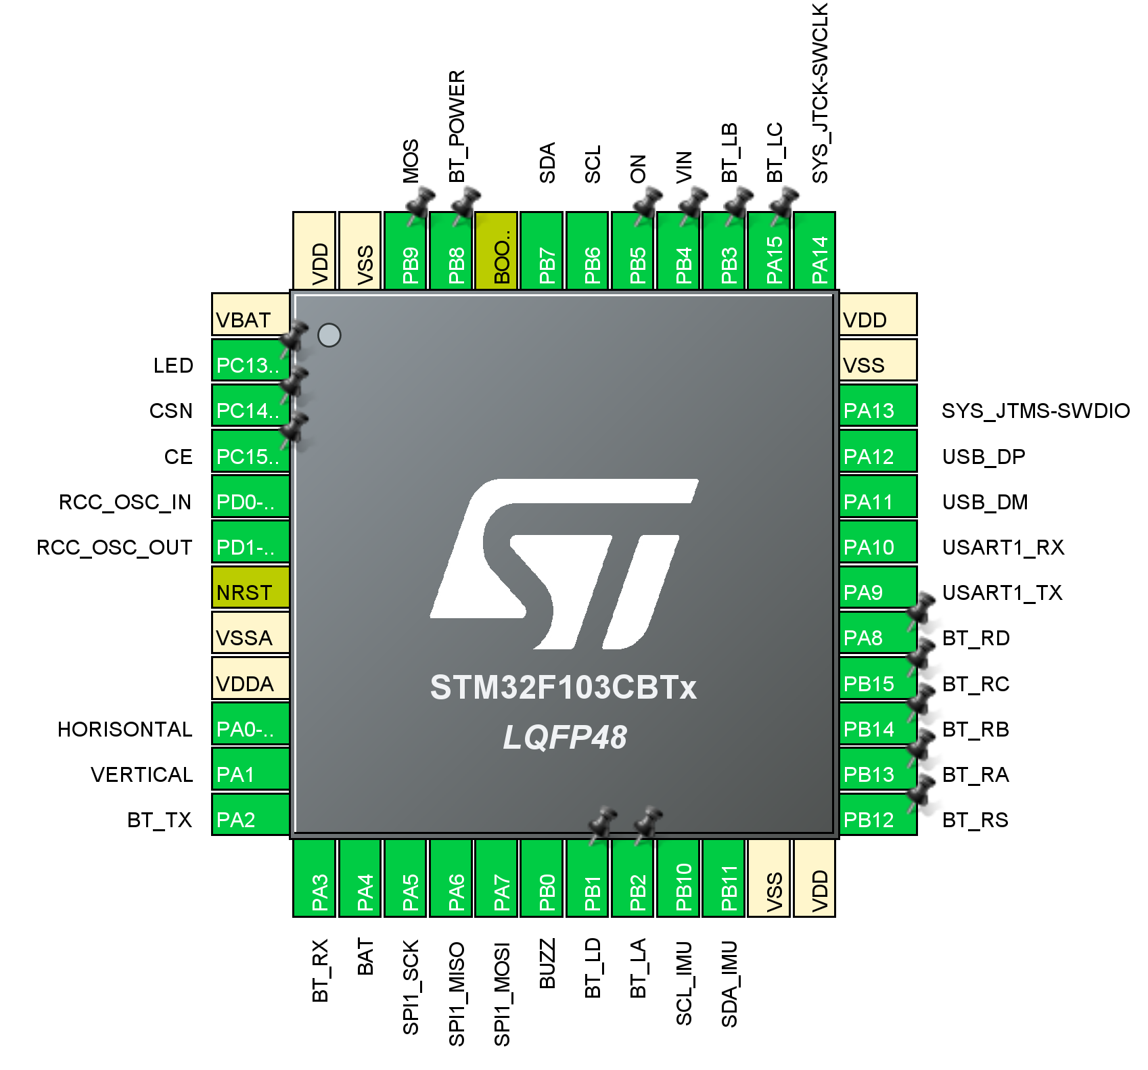
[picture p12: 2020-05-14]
sr_szablon_projekt/figures/cpu.PNG

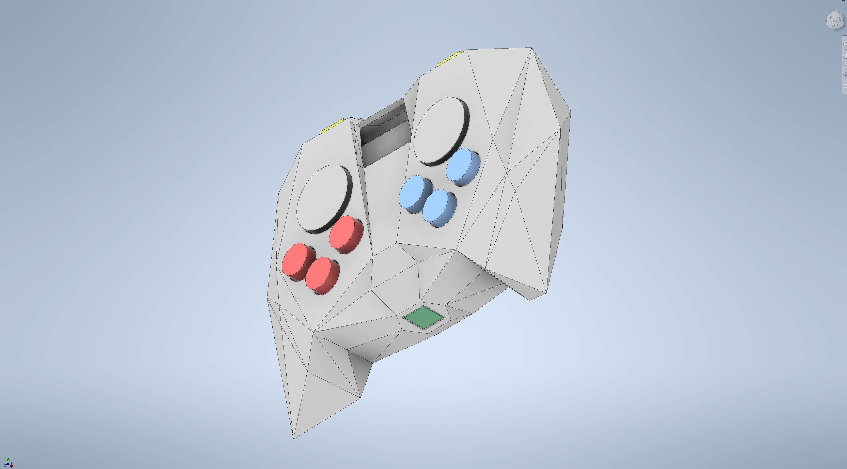
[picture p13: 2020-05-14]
sr_szablon_projekt/figures/obudowa_1.PNG

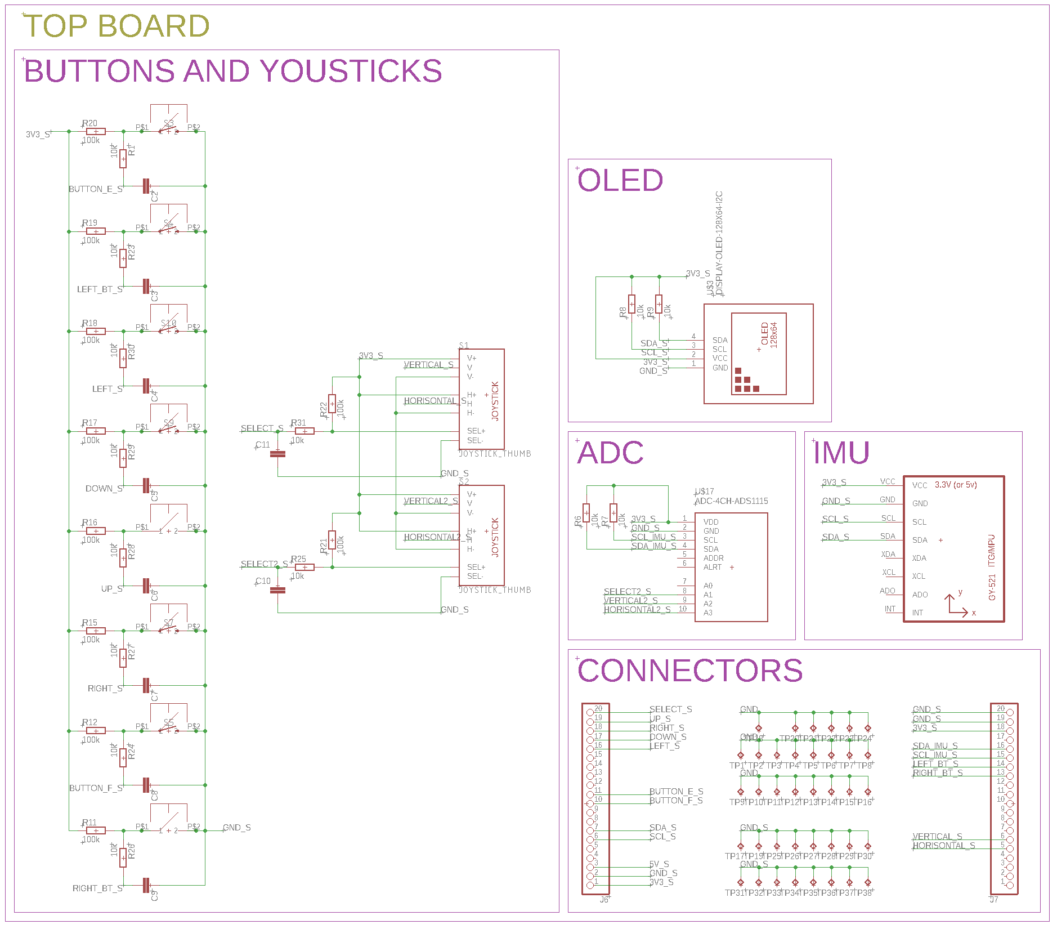
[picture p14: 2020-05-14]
sr_szablon_projekt/figures/sh_top.PNG

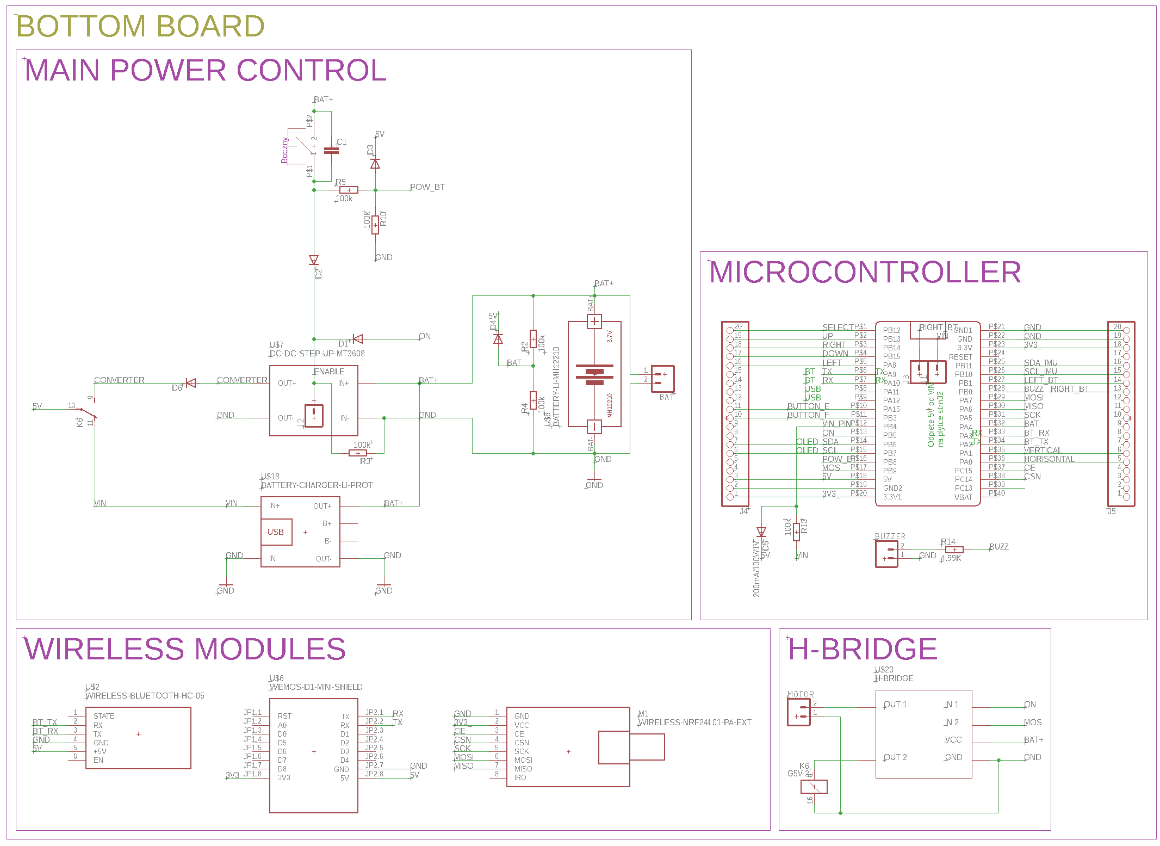
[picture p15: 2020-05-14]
sr_szablon_projekt/figures/sh_bot.PNG

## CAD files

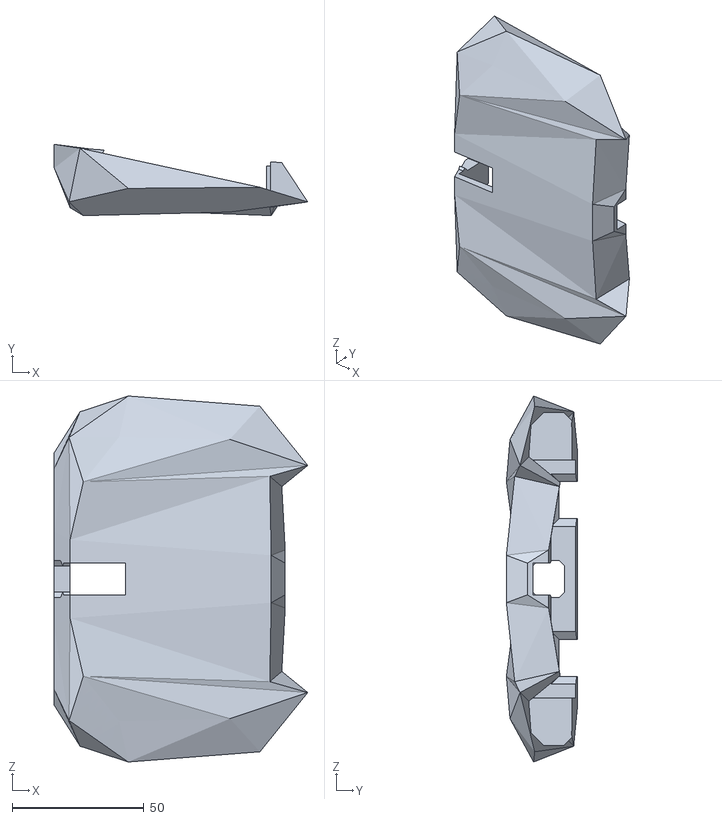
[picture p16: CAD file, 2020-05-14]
Czesci/Druk/SHELL_BOTTOM.obj
96.0 x 27.0 x 138.6

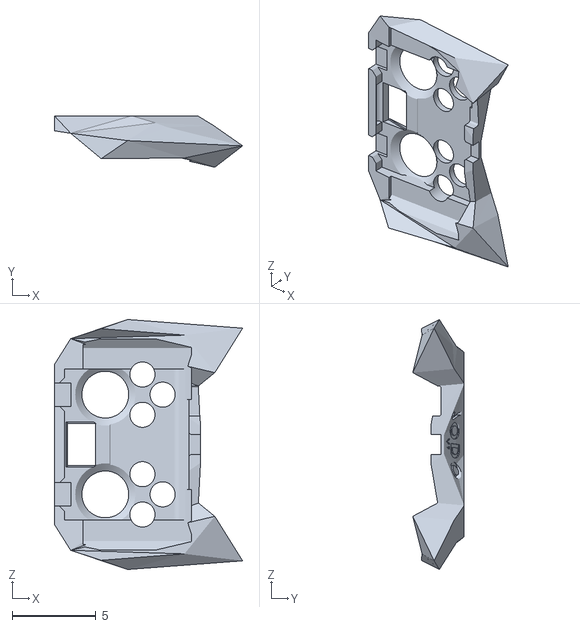
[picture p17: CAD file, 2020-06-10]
Czesci/Obudowa_v1_SHELL_Up.stl
11.3 x 3.08 x 15.0

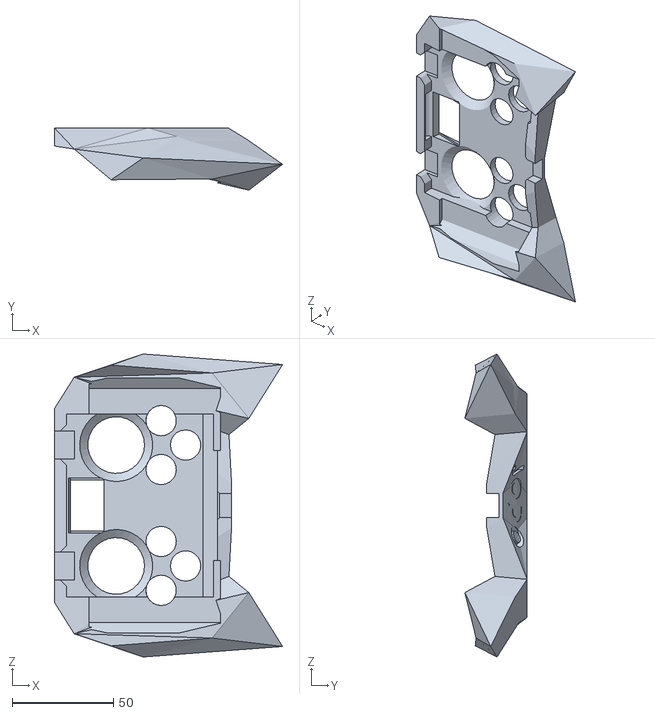
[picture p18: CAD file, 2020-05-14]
Czesci/Druk/SHELL_UP.obj
112.7 x 30.8 x 149.6

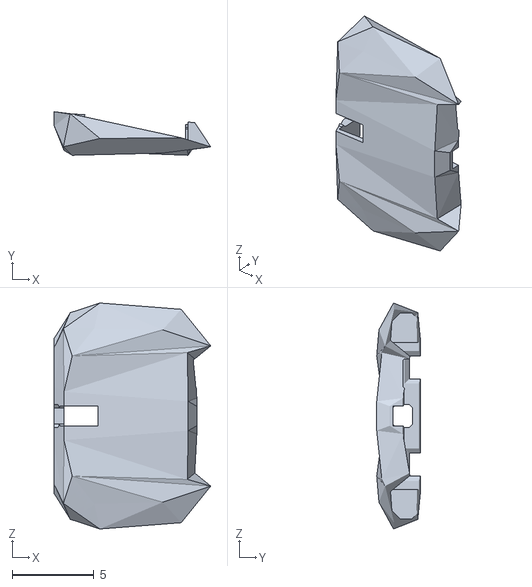
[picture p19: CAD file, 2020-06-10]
Czesci/Obudowa_v1_SHELL_Down.stl
9.60 x 2.67 x 13.9

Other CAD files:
Czesci/Assembly.iam
Czesci/Obudowa_v1.ipt
Czesci/Obudowa_v1_KONTORWERSYJNE.ipt
Czesci/Obudowa_v1_SHELL_1.ipt
Czesci/Obudowa_v1_SHELL_Down.obj
Czesci/Obudowa_v1_SHELL_Up.obj
Czesci/Obudowa_v1_calosc.ipt
Czesci/Obudowa_v1_profes.ipt
Czesci/Obudowa_v1_srodek.ipt
Czesci/Obudowa_v1_srodek_2d.ipt
Czesci/OldVersions/Assembly.0012.iam
Czesci/OldVersions/Obudowa_v1.0030.ipt
Czesci/OldVersions/Obudowa_v1.0031.ipt
Czesci/OldVersions/Obudowa_v1_KONTORWERSYJNE.0003.ipt
Czesci/OldVersions/Obudowa_v1_SHELL_1.0034.ipt
Czesci/OldVersions/Obudowa_v1_calosc.0006.ipt
Czesci/OldVersions/Obudowa_v1_profes.0001.ipt
Czesci/OldVersions/Obudowa_v1_profes.0002.ipt
Czesci/OldVersions/Obudowa_v1_srodek.0002.ipt
Czesci/OldVersions/Obudowa_v1_srodek_2d.0011.ipt
Czesci/kwadrat.ipt
Czesci/obrecz.ipt

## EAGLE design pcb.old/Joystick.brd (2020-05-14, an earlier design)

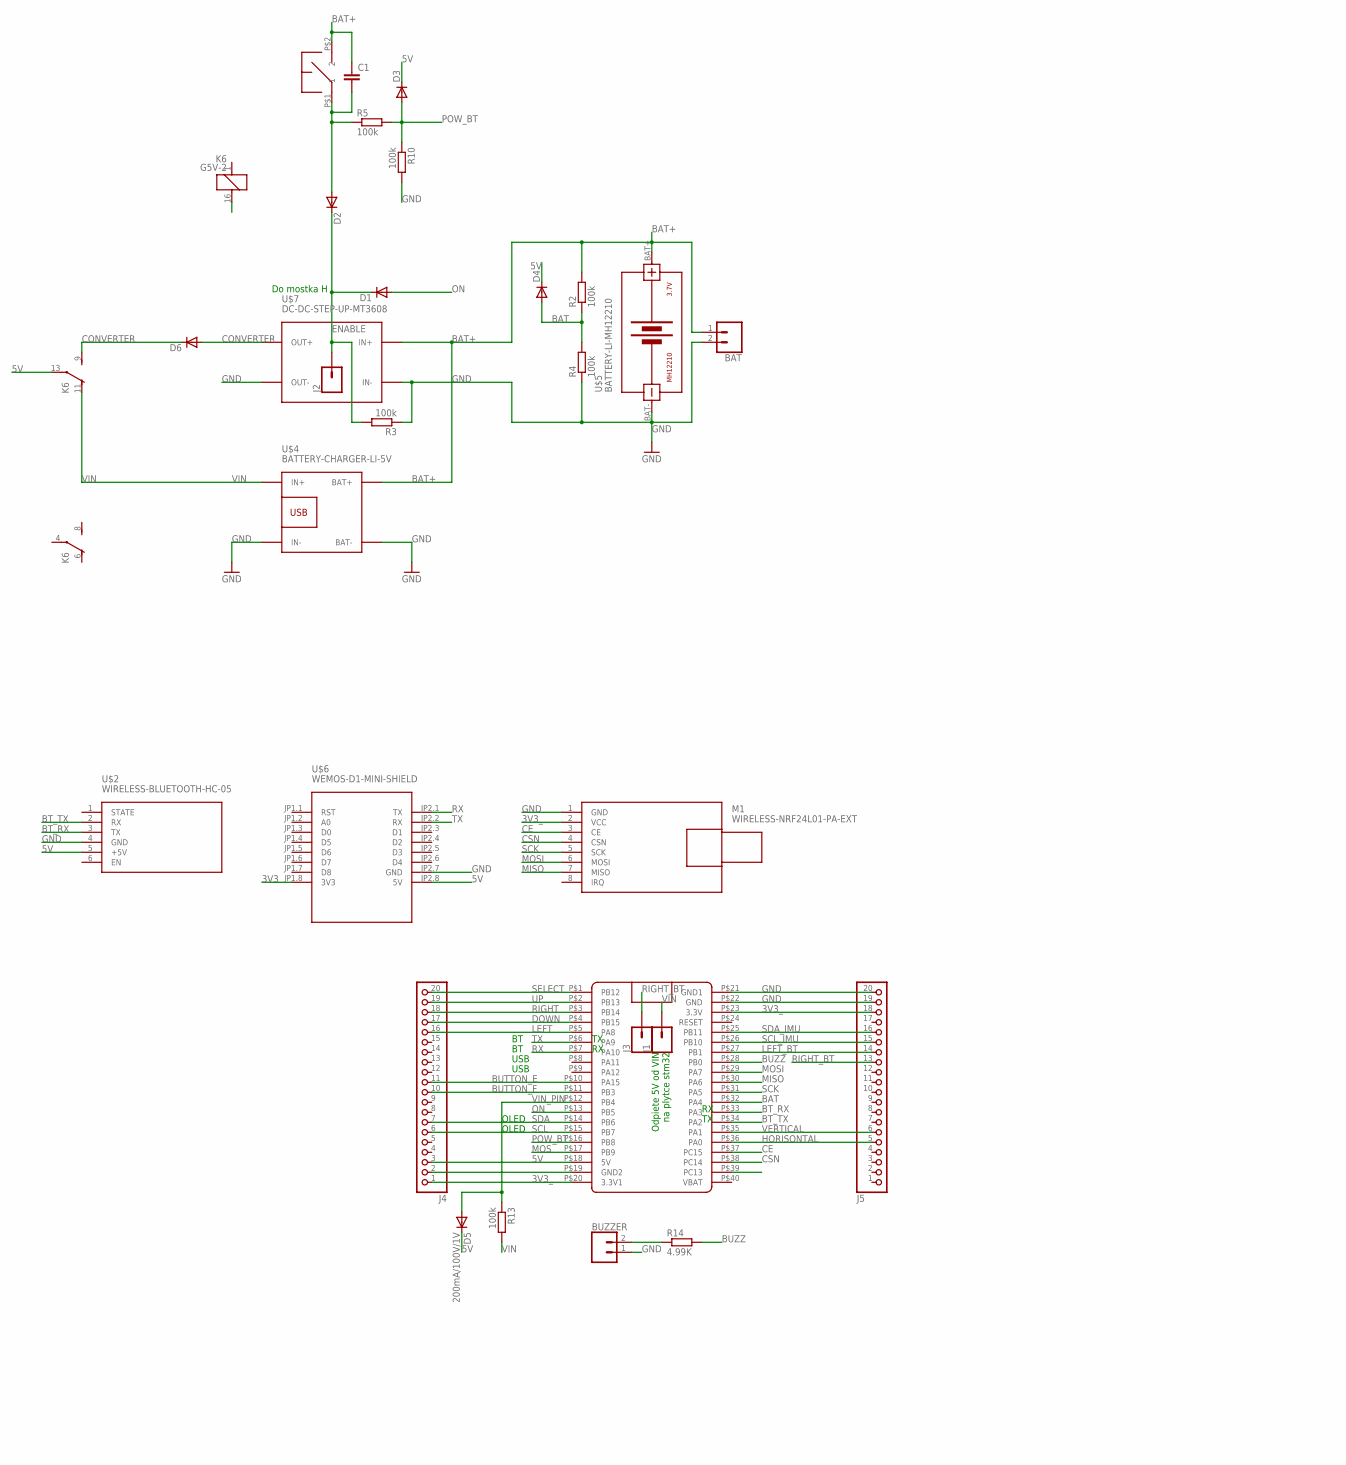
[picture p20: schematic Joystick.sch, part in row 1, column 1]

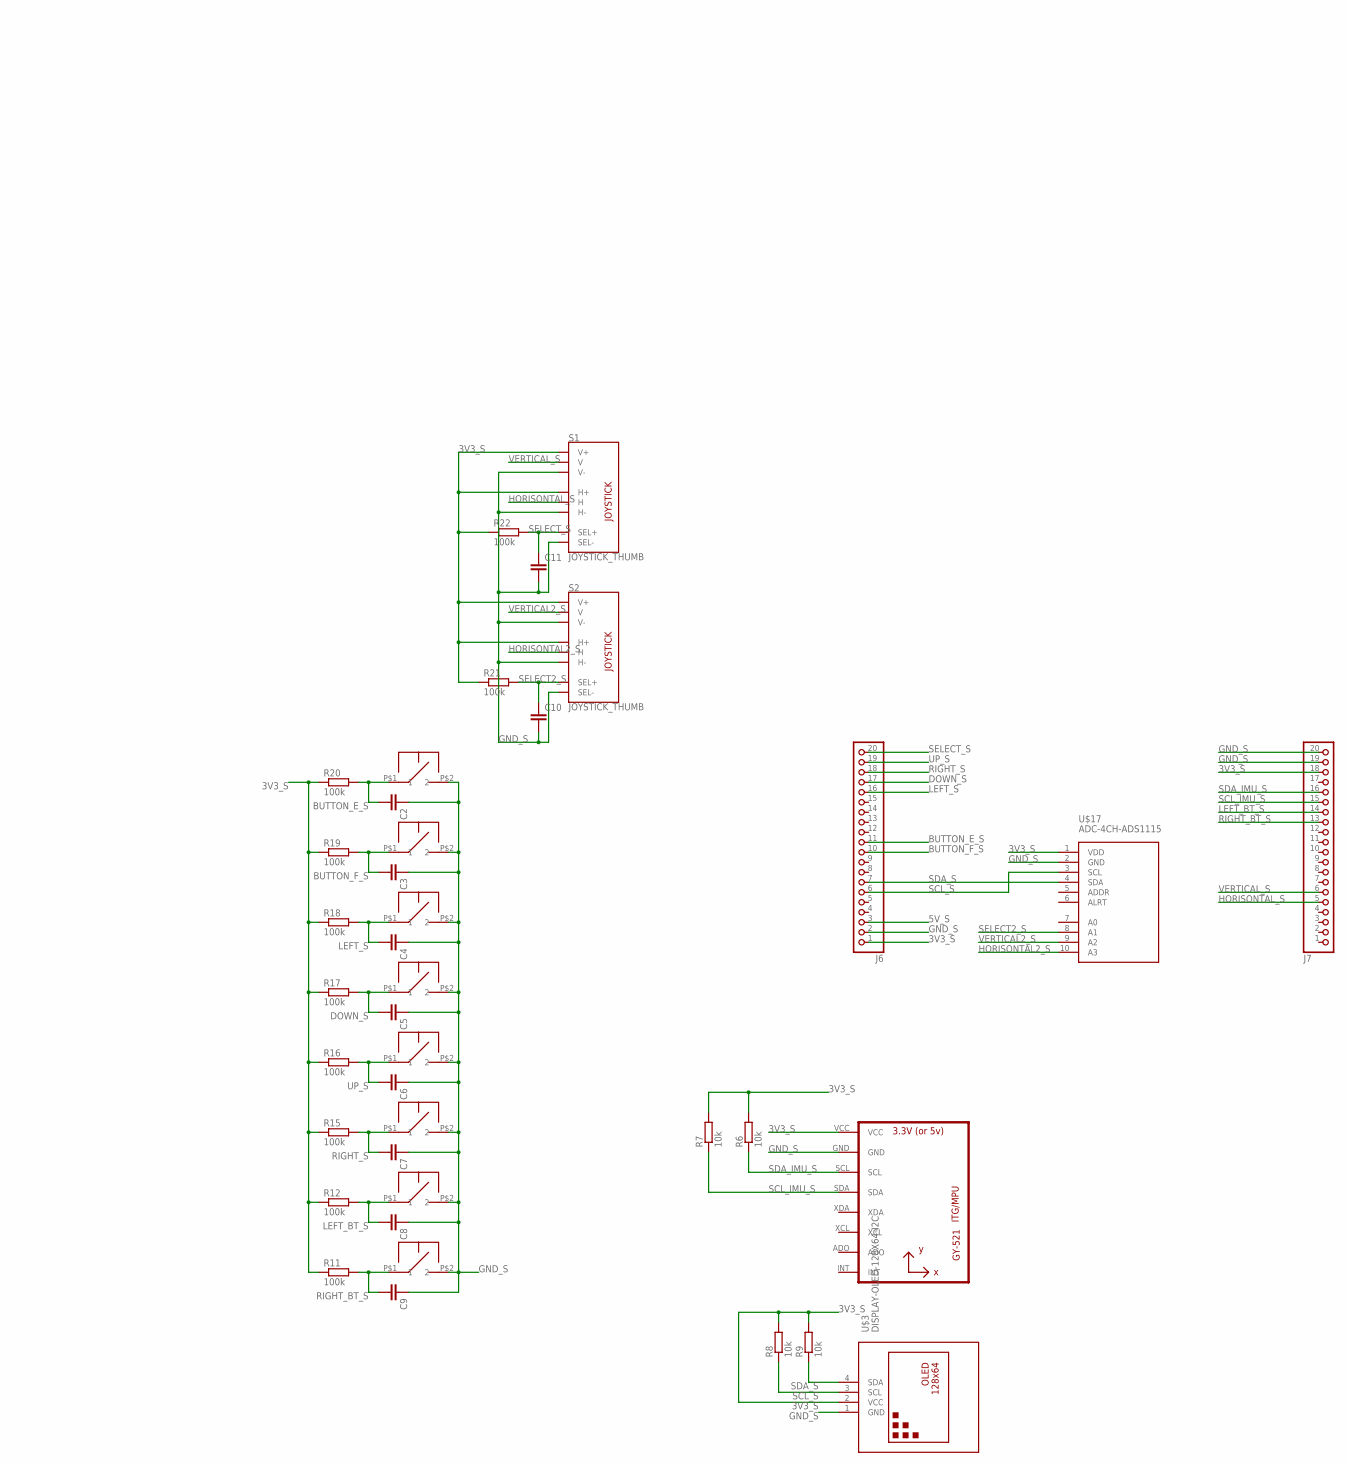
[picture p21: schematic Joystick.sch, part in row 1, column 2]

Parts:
BAT: CONN_02; 1X02
BUZZER: CONN_02; 1X02
C1, C2, C3, C4, C5, C6, C7, C8, C9, C10, C11: C-EUC1206; C1206
D1, D2, D3, D4, D5, D6: 200mA/100V/1V; DO214AC
J1, J2, J3: CONN_01; 1X01
J4, J5, J6, J7: PINHD-1X20; 1X20
K6: G5V-2
M1: WIRELESS-NRF24L01-PA-EXT
R2, R3, R4, R5, R10, R11, R12, R13, R15, R16, R17, R18, R19, R20, R21, R22: 100k; R0805
R6, R7, R8, R9: 10k; R0805
R14: 4.99K; R0805
S1, S2: JOYSTICK_THUMB; JOYSTICK
U1: GY-521MPU6050; GY-521
U$1: BLUE_PILL
U$2: WIRELESS-BLUETOOTH-HC-05
U$3: DISPLAY-OLED-128X64-I2C
U$4: BATTERY-CHARGER-LI-5V
U$5: BATTERY-LI-MH12210
U$6: WEMOS-D1-MINI-SHIELD
U$7: DC-DC-STEP-UP-MT3608
U$8, U$9, U$10, U$11, U$12, U$13, U$14, U$15, U$16: MOUSE_BT
U$17: ADC-4CH-ADS1115

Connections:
3V3: U$6.JP1.8 (3V3)
3V3_: J4.1, J5.18, M1.2 (VCC), U$1.P$20 (3.3V1), U$1.P$23 (3.3V)
3V3_S: J6.1, J7.18, R6.2, R7.2, R8.2, R9.2, R11.1, R12.1, R15.1, R16.1, R17.1, R18.1, R19.1, R20.1, R21.1, R22.1, S1.H1 (H+), S1.V1 (V+), S2.H1 (H+), S2.V1 (V+), U1.VCC, U$3.2 (VCC), U$17.1 (VDD)
5V: D3.C, D4.C, D5.C, J4.3, K6.13, U$1.P$18 (5V), U$2.5 (+5V), U$6.JP2.8 (5V)
5V_S: J6.3
ASD: BUZZER.2, R14.1
BAT: D4.A, R2.1, R4.2, U$1.P$32 (PA4)
BAT+: BAT.1, C1.1, R2.2, U$4.BAT+, U$5.BAT+, U$7.IN+, U$8.P$2 (2)
BT_RX: U$1.P$33 (PA3), U$2.3 (TX)
BT_TX: U$1.P$34 (PA2), U$2.2 (RX)
BUTTON: C1.2, D2.A, R5.1, U$8.P$1 (1)
BUTTON_E: J4.11, U$1.P$10 (PA15)
BUTTON_E_S: C2.2, J6.11, R20.2, U$11.P$1 (1)
BUTTON_F: J4.10, U$1.P$11 (PB3)
BUTTON_F_S: C3.2, J6.10, R19.2, U$15.P$1 (1)
BUZZ: R14.2, U$1.P$28 (PB0)
CE: M1.3 (CE), U$1.P$37 (PC15)
CONVERTER: D6.C, K6.9 (S)
CSN: M1.4 (CSN), U$1.P$38 (PC14)
DOWN: J4.17, U$1.P$4 (PB15)
DOWN_S: C5.2, J6.17, R17.2, U$14.P$1 (1)
ENABLE: D1.C, D2.C, J2.1, R3.2
GGJHGJ: U$1.P$39 (PC13)
GND: BAT.2, BUZZER.1, J4.2, J5.19, J5.20, M1.1 (GND), R3.1, R4.1, R10.2, U$1.P$19 (GND2), U$1.P$21 (GND1), U$1.P$22 (GND), U$2.4 (GND), U$4.BAT-, U$4.IN-, U$5.BAT-, U$6.JP2.7 (GND), U$7.IN-, U$7.OUT-
GND_S: C2.1, C3.1, C4.1, C5.1, C6.1, C7.1, C8.1, C9.1, C10.2, C11.2, J6.2, J7.19, J7.20, S1.B2A (SEL-), S1.H3 (H-), S1.V3 (V-), S2.B2A (SEL-), S2.H3 (H-), S2.V3 (V-), U1.GND, U$3.1 (GND), U$9.P$2 (2), U$10.P$2 (2), U$11.P$2 (2), U$12.P$2 (2), U$13.P$2 (2), U$14.P$2 (2), U$15.P$2 (2), U$16.P$2 (2), U$17.2 (GND)
HORISONTAL: J5.5, U$1.P$36 (PA0)
HORISONTAL2_S: S2.H2 (H), U$17.10 (A3)
HORISONTAL_S: J7.5, S1.H2 (H)
LEFT: J4.16, U$1.P$5 (PA8)
LEFT_BT: J5.14, U$1.P$27 (PB1)
LEFT_BT_S: C8.2, J7.14, R12.2, U$10.P$1 (1)
LEFT_S: C4.2, J6.16, R18.2, U$16.P$1 (1)
MISO: M1.7 (MISO), U$1.P$30 (PA6)
MOS: U$1.P$17 (PB9)
MOSI: M1.6 (MOSI), U$1.P$29 (PA7)
unnamed: D6.A, U$7.OUT+
ON: D1.A, U$1.P$13 (PB5)
POW_BT: D3.A, R5.2, R10.1, U$1.P$16 (PB8)
RIGHT: J4.18, U$1.P$3 (PB14)
RIGHT_BT: J3.1, J5.13
RIGHT_BT_S: C9.2, J7.13, R11.2, U$9.P$1 (1)
RIGHT_S: C7.2, J6.18, R15.2, U$13.P$1 (1)
RX: U$1.P$7 (PA10), U$6.JP2.1 (TX)
SCK: M1.5 (SCK), U$1.P$31 (PA5)
SCL: J4.6, U$1.P$15 (PB7)
SCL_IMU: J5.15, U$1.P$26 (PB10)
SCL_IMU_S: J7.15, R7.1, U1.SDA
SCL_S: J6.6, R8.1, U$3.3 (SCL), U$17.3 (SCL)
SDA: J4.7, U$1.P$14 (PB6)
SDA_IMU: J5.16, U$1.P$25 (PB11)
SDA_IMU_S: J7.16, R6.1, U1.SCL
SDA_S: J6.7, R9.1, U$3.4 (SDA), U$17.4 (SDA)
SELECT: J4.20, U$1.P$1 (PB12)
SELECT2_S: C10.1, R21.2, S2.B1A (SEL+), U$17.8 (A1)
SELECT_S: C11.1, J6.20, R22.2, S1.B1A (SEL+)
TX: U$1.P$6 (PA9), U$6.JP2.2 (RX)
UP: J4.19, U$1.P$2 (PB13)
UP_S: C6.2, J6.19, R16.2, U$12.P$1 (1)
VERTICAL: J5.6, U$1.P$35 (PA1)
VERTICAL2_S: S2.V2 (V), U$17.9 (A2)
VERTICAL_S: J7.6, S1.V2 (V)
VIN: J1.1, K6.11 (O), R13.2, U$4.IN+
VIN_PIN: D5.A, R13.1, U$1.P$12 (PB4)

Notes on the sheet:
Odpiete 5V od VIN na plytce stm32
USB
OLED
Do mostka H

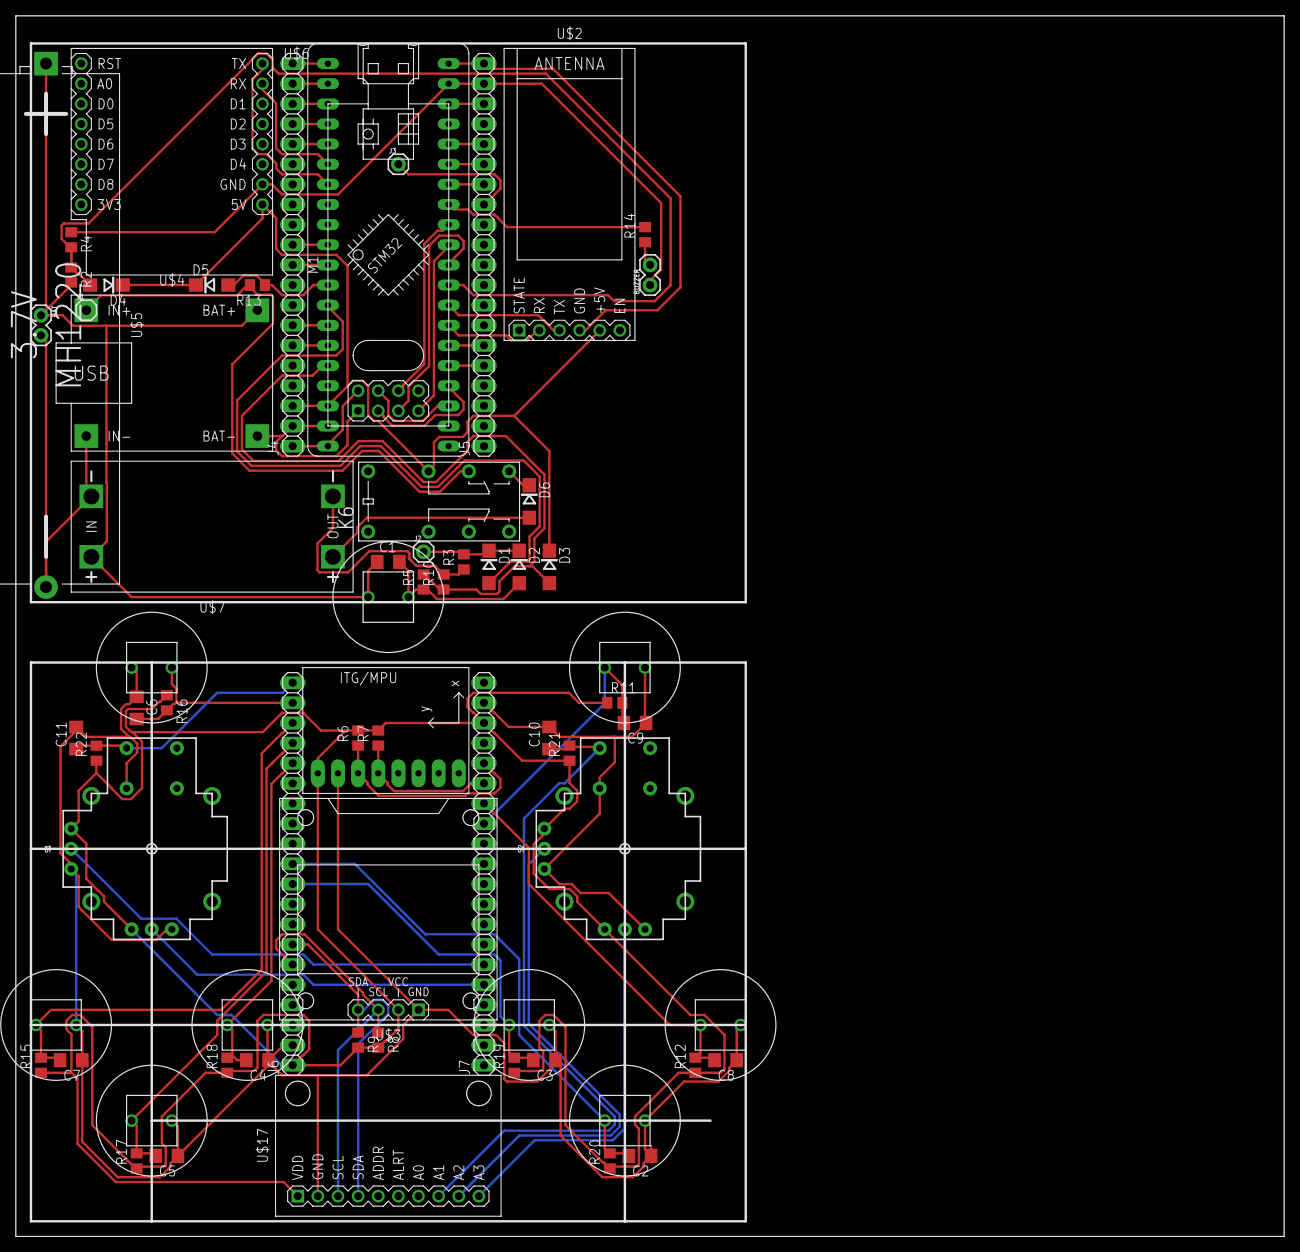
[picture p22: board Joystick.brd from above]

Board: 4 copper layers, 160.0 x 154.0 mm, 69 parts (0 on the bottom side), 59 nets.

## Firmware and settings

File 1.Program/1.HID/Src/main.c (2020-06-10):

/**
  ******************************************************************************
  * File Name          : main.c
  * Description        : Main program body
  ******************************************************************************
  *
  * Copyright (c) 2020 STMicroelectronics International N.V. 
  * All rights reserved.
  *
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
  ******************************************************************************
  */
/* Includes ------------------------------------------------------------------*/
#include "main.h"
#include "stm32f1xx_hal.h"
#include "usb_device.h"

/* USER CODE BEGIN Includes */
#include "usbd_custom_hid_if.h"
#include "usbd_customhid.h"

#include "string.h"


#include "ssd1306.h"
#include "i2c-lcd.h"
//#include "stdio.h"

/* USER CODE END Includes */

ADC_HandleTypeDef hadc1;

I2C_HandleTypeDef hi2c1;
I2C_HandleTypeDef hi2c2;

SPI_HandleTypeDef hspi1;

TIM_HandleTypeDef htim3;

UART_HandleTypeDef huart1;
UART_HandleTypeDef huart2;

/* USER CODE BEGIN PV */
/* USER CODE END PV */

void SystemClock_Config(void);
void Error_Handler(void);
static void MX_GPIO_Init(void);
static void MX_ADC1_Init(void);
static void MX_I2C1_Init(void);
static void MX_I2C2_Init(void);
static void MX_SPI1_Init(void);
static void MX_TIM3_Init(void);
static void MX_USART1_UART_Init(void);
static void MX_USART2_UART_Init(void);

void HAL_TIM_MspPostInit(TIM_HandleTypeDef *htim);
                                

/* USER CODE BEGIN PFP */

/* USER CODE END PFP */

/* USER CODE BEGIN 0 */

uint8_t V_Value;
uint8_t H_Value;
uint8_t Buttons_1 = 0;
uint8_t Buttons_2 = 0;

//extern USBD_HandleTypeDef  *hUsbDeviceFS;
uint8_t dataToSend[20] = {0x00, 0x14, 0x01, 0xEE, 0x0F, 0x00, 0x0F, 0x00, 0xFF, 0xFF, 0x00, 0x00, 0x00, 0x00, 0x00, 0x00, 0x00, 0x00, 0x00, 0x00};
//                        butns|size|     |     | lt  | rt  | lx        | ly        | rx        | ry        | unused
//                                    b10 & b9  & b7  & b8  & dr  & dl  & dd  & du
//                                          b4  & b3  & b2  & b1  & b0  & nusd & xbox & b6  & b5
uint8_t dataReceived[8]; // not used yet
uint16_t adcFrom [3];
int16_t adcFromBuffer [3];

uint32_t ticksNextBlink = 0;
uint32_t ticksForBlink = 1000/60;

uint8_t buttonPressed = 0;

uint8_t EncoderState = 0;
uint8_t EncoderLastState = 0;
uint8_t Encoder_A = 0;
uint8_t Encoder_B = 0;

uint16_t WheelValue = 2048;


/*
uint8_t readA(){ return HAL_GPIO_ReadPin(GPIOA, GPIO_PIN_3); }
uint8_t readB(){ return HAL_GPIO_ReadPin(GPIOA, GPIO_PIN_4); }
uint8_t readX(){ return HAL_GPIO_ReadPin(GPIOA, GPIO_PIN_5); }
uint8_t readY(){ return HAL_GPIO_ReadPin(GPIOA, GPIO_PIN_6); }
uint8_t readMode(){ return HAL_GPIO_ReadPin(GPIOB, GPIO_PIN_1); }
uint8_t readLB(){ return 0; }
uint8_t readRB(){ return 0; }
uint8_t readDU(){ return 0; }
uint8_t readDD(){ return 0; }
uint8_t readDL(){ return 0; }
uint8_t readDR(){ return 0; }
uint8_t readStart(){ return HAL_GPIO_ReadPin(GPIOB, GPIO_PIN_0); }
uint8_t readBack(){ return HAL_GPIO_ReadPin(GPIOA, GPIO_PIN_7); }
uint8_t readLS(){ return 0; }
uint8_t readRS(){ return 0; }
*/

void UpdateWheel()
{
	Encoder_A = HAL_GPIO_ReadPin(GPIOB, GPIO_PIN_0);
	Encoder_B = HAL_GPIO_ReadPin(GPIOB, GPIO_PIN_1) << 1;
	EncoderState = Encoder_A | Encoder_B;


		//HAL_GPIO_WritePin(GPIOC, GPIO_PIN_13, !HAL_GPIO_ReadPin(GPIOC, GPIO_PIN_13));
		if (EncoderLastState != EncoderState){
		    switch (EncoderState) {
		      case 0:
		        if (EncoderLastState == 2){
		        	WheelValue += 24;
		          //cw = 1;
		        }
		        else if(EncoderLastState == 1){
		        	WheelValue -= 24;
		          //cw = -1;
		        }
		        break;
		      case 1:
		        if (EncoderLastState == 0){
		        	WheelValue += 24;
		          //cw = 1;
		        }
		        else if(EncoderLastState == 3){
		        	WheelValue -= 24;
		          //cw = -1;
		        }
		        break;
		      case 2:
		        if (EncoderLastState == 3){
		        	WheelValue += 24;
		          //cw = 1;
		        }
		        else if(EncoderLastState == 0){
		        	WheelValue -= 24;
		          //cw = -1;
		        }
		        break;
		      case 3:
		        if (EncoderLastState == 1){
		        	WheelValue += 24;
		          //cw = 1;
		        }
		        else if(EncoderLastState == 2){
		        	WheelValue -= 24;
		          //cw = -1;
		        }
		        break;
		    }
		  }

		EncoderLastState = EncoderState;
}

void updateButtons()
{
	// btns |rs|, |ls|, |select|, |start|, |dr|, |dl|, |dd|, |du|
	dataToSend[2] = 0;
	//dataToSend[2] = Buttons_1;
	/*		// Chwilowo
	dataToSend[2] |= (readDU() & 1) << 0;
	dataToSend[2] |= (readDD() & 1) << 1;
	dataToSend[2] |= (readDL() & 1) << 2;
	dataToSend[2] |= (readDR() & 1) << 3;
	dataToSend[2] |= (readStart() & 1) << 4;
	dataToSend[2] |= (readBack()  & 1) << 5;
	dataToSend[2] |= (readLS() & 1) << 6;
	dataToSend[2] |= (readRS() & 1) << 7;
	*/
	// btns |y|, |x|, |b|, |a|, _, _, |rb|, |lb|

	dataToSend[3] = 0;
	//dataToSend[3] = Buttons_2;
	/*		// Chwilowo
	dataToSend[3] |= (readLB() & 1) << 0;
	dataToSend[3] |= (readRB() & 1) << 1;
	dataToSend[3] |= (0 & 1) << 2;
	dataToSend[3] |= (0 & 1) << 3;
	dataToSend[3] |= (readA()  & 1) << 4;
	dataToSend[3] |= (readB()  & 1) << 5;
	dataToSend[3] |= (readX()  & 1) << 6;
	dataToSend[3] |= (readY()  & 1) << 7;
	*/
	// z = -left-trigger zone _ 0 _ right-trigger zone
	/*
	adcFromBuffer[2] = (int16_t)adcFrom[2];
	adcFromBuffer[2] /= 8;
	adcFromBuffer[2] = adcFromBuffer[2] - 255;
	*/
	// left & right triggers
	dataToSend[4] = 0; //left
	dataToSend[5] = 0; //right
	/*
	if (adcFromBuffer[2] < 0)
		dataToSend[4] = (uint8_t)(256 - (adcFromBuffer[2] & 0xFF));
	else
		dataToSend[5] = adcFromBuffer[2] & 0xFF;
		*/
///////////////////////////////////////////////////////////////////////////// lx
	adcFromBuffer[1] = WheelValue;//(int16_t)adcFrom[0];
	adcFromBuffer[1] -= 2048;
	adcFromBuffer[1] *= 16;
	dataToSend[6] = adcFromBuffer[1] & 0xFF;
	dataToSend[7] = (adcFromBuffer[1] >> 8) & 0xFF;
	/*
	adcFromBuffer[1] = (int16_t)V_Value;
	adcFromBuffer[1] -= 110;
	//adcFromBuffer[1] -= 1;		// Aby nie przekroczyc zakresu
	adcFromBuffer[1] *= -256;
	dataToSend[6] = adcFromBuffer[1] & 0xFF;
	dataToSend[7] = (adcFromBuffer[1] >> 8) & 0xFF;
///////////////////////////////////////////////////////////////////////////// ly
	adcFromBuffer[0] = (int16_t)H_Value;
	adcFromBuffer[0] -= 110;
	//adcFromBuffer[1] -= 1;		// Aby nie przekroczyc zakresu
	adcFromBuffer[0] *= -256;
	dataToSend[8] = adcFromBuffer[0] & 0xFF;
	dataToSend[9] = (adcFromBuffer[0] >> 8) & 0xFF;
	*/
	//adcFromBuffer[0] = (int16_t)adcFrom[0];
	//adcFromBuffer[0] -= 2048;
	//adcFromBuffer[0] *= 16;
	adcFromBuffer[0] = 0;
	dataToSend[8] = adcFromBuffer[0] & 0xFF;
	dataToSend[9] = (adcFromBuffer[0] >> 8) & 0xFF;

/////////////////////////////////////////////////////////////////////////////
	// rx
	dataToSend[10] = 0x7F;
	dataToSend[11] = 0xFF;
	// ry
	dataToSend[12] = 0x7F;
	dataToSend[13] = 0xFF;
}
/* USER CODE END 0 */

int main(void)
{

  /* USER CODE BEGIN 1 */

	//Encoder_A = HAL_GPIO_ReadPin(GPIOB, GPIO_PIN_0);
	//Encoder_B = HAL_GPIO_ReadPin(GPIOB, GPIO_PIN_1) << 1;
	//EncoderLastState = Encoder_A | Encoder_B;
  /* USER CODE END 1 */

  /* MCU Configuration----------------------------------------------------------*/

  /* Reset of all peripherals, Initializes the Flash interface and the Systick. */
  HAL_Init();

  /* Configure the system clock */
  SystemClock_Config();

  /* Initialize all configured peripherals */
  MX_GPIO_Init();
  MX_ADC1_Init();
  MX_I2C1_Init();
  MX_I2C2_Init();
  MX_SPI1_Init();
  MX_TIM3_Init();
  MX_USART1_UART_Init();
  MX_USART2_UART_Init();
  MX_USB_DEVICE_Init();

  /* USER CODE BEGIN 2 */
  //HAL_ADC_Start_DMA(&hadc1, (uint32_t*)&adcFrom, 3); // for analog reading start periph-to-mem dma for 3 pins. settings in CUBE
  //adcFrom[0] = 0;
  //adcFrom[1] = 0;
  // INICJALIZACJA EKRANU
  /*
	lcd_init ();
	uint8_t check = SSD1306_Init ();
	SSD1306_Fill (0);
	SSD1306_UpdateScreen(); //display
	SSD1306_GotoXY (10,10);
	SSD1306_Puts ("HELLO", &Font_11x18, 1);
	SSD1306_GotoXY (10, 30);
	SSD1306_Puts ("WORLD !!", &Font_11x18, 1);
	SSD1306_UpdateScreen(); //display
	//while((HAL_I2C_IsDeviceReady (&hi2c1, 0x4E, 10, 100)));
	//lcd_send_string ("HELLO WORLD !!");
	SSD1306_Fill (0);
	SSD1306_UpdateScreen(); //display

	HAL_Delay(100);
	*/
  /* USER CODE END 2 */

  /* Infinite loop */
  /* USER CODE BEGIN WHILE */

  //printf("Elo\n");
  //char buff[2];


  //HAL_GPIO_WritePin( GPIOC, GPIO_PIN_13, 1);

  while (1)
    {
	  /*
  	  char String[16];

	  int n;
	  uint8_t Start_Bit;

	  HAL_UART_Receive(&huart3, &Start_Bit, 2 ,1000);		// Blokujace bo nie ma pzrerwa�
	  HAL_GPIO_WritePin(GPIOC, GPIO_PIN_13, !HAL_GPIO_ReadPin(GPIOC, GPIO_PIN_13));
	  if (Start_Bit == 1)
	  {
		  U3S('1');

		  HAL_UART_Receive(&huart3, &H_Value, 1 ,1000);		// Blokujace bo nie ma pzrerwa�
		  n=sprintf (String, "Y: %d    ", H_Value);
		  SSD1306_GotoXY (0,10);
		  SSD1306_Puts (String, &Font_7x10, 1);

		  HAL_UART_Receive(&huart3, &V_Value, 1 ,1000);		// Blokujace bo nie ma pzrerwa�
		  n=sprintf (String, "X: %d    ", V_Value);
		  SSD1306_GotoXY (0,20);
		  SSD1306_Puts (String, &Font_7x10, 1);

		  HAL_UART_Receive(&huart3, &Buttons_1, 1 ,1000);		// Blokujace bo nie ma pzrerwa�
		  n=sprintf (String, "B_1: %d    ", Buttons_1);
		  SSD1306_GotoXY (0,30);
		  SSD1306_Puts (String, &Font_7x10, 1);

		  HAL_UART_Receive(&huart3, &Buttons_2, 1 ,1000);		// Blokujace bo nie ma pzrerwa�
		  n=sprintf (String, "B_2: %d    ", Buttons_2);
		  SSD1306_GotoXY (0,40);
		  SSD1306_Puts (String, &Font_7x10, 1);
	  }
	  else
	  {
		  // Odebralismy przypadkiem syf jakis
		 SSD1306_GotoXY (0,10);
		 SSD1306_Puts ("Error_01", &Font_7x10, 1);
		 SSD1306_GotoXY (0,20);
		 n=sprintf (String, "Recived: %d    ", Start_Bit);
		 SSD1306_Puts (String, &Font_7x10, 1);
	  }
	  SSD1306_UpdateScreen(); //display
*/
	  UpdateWheel();

	  //if (HAL_GetTick() > ticksNextBlink)
	  {
		  ticksNextBlink = HAL_GetTick() + ticksForBlink;
		  updateButtons();

		  USBD_CUSTOM_HID_SendReport(&hUsbDeviceFS, dataToSend, 20);

	  }

  /* USER CODE END WHILE */

  /* USER CODE BEGIN 3 */

  }
  /* USER CODE END 3 */

}

/** System Clock Configuration
*/
void SystemClock_Config(void)
{

  RCC_OscInitTypeDef RCC_OscInitStruct;
  RCC_ClkInitTypeDef RCC_ClkInitStruct;
  RCC_PeriphCLKInitTypeDef PeriphClkInit;

    /**Initializes the CPU, AHB and APB busses clocks 
    */
  RCC_OscInitStruct.OscillatorType = RCC_OSCILLATORTYPE_HSE;
  RCC_OscInitStruct.HSEState = RCC_HSE_ON;
  RCC_OscInitStruct.HSEPredivValue = RCC_HSE_PREDIV_DIV1;
  RCC_OscInitStruct.HSIState = RCC_HSI_ON;
  RCC_OscInitStruct.PLL.PLLState = RCC_PLL_ON;
  RCC_OscInitStruct.PLL.PLLSource = RCC_PLLSOURCE_HSE;
  RCC_OscInitStruct.PLL.PLLMUL = RCC_PLL_MUL9;
  if (HAL_RCC_OscConfig(&RCC_OscInitStruct) != HAL_OK)
  {
    Error_Handler();
  }

    /**Initializes the CPU, AHB and APB busses clocks 
    */
  RCC_ClkInitStruct.ClockType = RCC_CLOCKTYPE_HCLK|RCC_CLOCKTYPE_SYSCLK
                              |RCC_CLOCKTYPE_PCLK1|RCC_CLOCKTYPE_PCLK2;
  RCC_ClkInitStruct.SYSCLKSource = RCC_SYSCLKSOURCE_PLLCLK;
  RCC_ClkInitStruct.AHBCLKDivider = RCC_SYSCLK_DIV1;
  RCC_ClkInitStruct.APB1CLKDivider = RCC_HCLK_DIV2;
  RCC_ClkInitStruct.APB2CLKDivider = RCC_HCLK_DIV1;

  if (HAL_RCC_ClockConfig(&RCC_ClkInitStruct, FLASH_LATENCY_2) != HAL_OK)
  {
    Error_Handler();
  }

  PeriphClkInit.PeriphClockSelection = RCC_PERIPHCLK_ADC|RCC_PERIPHCLK_USB;
  PeriphClkInit.AdcClockSelection = RCC_ADCPCLK2_DIV6;
  PeriphClkInit.UsbClockSelection = RCC_USBCLKSOURCE_PLL_DIV1_5;
  if (HAL_RCCEx_PeriphCLKConfig(&PeriphClkInit) != HAL_OK)
  {
    Error_Handler();
  }

    /**Configure the Systick interrupt time 
    */
  HAL_SYSTICK_Config(HAL_RCC_GetHCLKFreq()/1000);

    /**Configure the Systick 
    */
  HAL_SYSTICK_CLKSourceConfig(SYSTICK_CLKSOURCE_HCLK);

  /* SysTick_IRQn interrupt configuration */
  HAL_NVIC_SetPriority(SysTick_IRQn, 0, 0);
}

/* ADC1 init function */
static void MX_ADC1_Init(void)
{

  ADC_ChannelConfTypeDef sConfig;

    /**Common config 
    */
  hadc1.Instance = ADC1;
  hadc1.Init.ScanConvMode = ADC_SCAN_DISABLE;
  hadc1.Init.ContinuousConvMode = DISABLE;
  hadc1.Init.DiscontinuousConvMode = DISABLE;
  hadc1.Init.ExternalTrigConv = ADC_SOFTWARE_START;
  hadc1.Init.DataAlign = ADC_DATAALIGN_RIGHT;
  hadc1.Init.NbrOfConversion = 1;
  if (HAL_ADC_Init(&hadc1) != HAL_OK)
  {
    Error_Handler();
  }

    /**Configure Regular Channel 
    */
  sConfig.Channel = ADC_CHANNEL_0;
  sConfig.Rank = 1;
  sConfig.SamplingTime = ADC_SAMPLETIME_1CYCLE_5;
  if (HAL_ADC_ConfigChannel(&hadc1, &sConfig) != HAL_OK)
  {
    Error_Handler();
  }

}

/* I2C1 init function */
static void MX_I2C1_Init(void)
{

  hi2c1.Instance = I2C1;
  hi2c1.Init.ClockSpeed = 100000;
  hi2c1.Init.DutyCycle = I2C_DUTYCYCLE_2;
  hi2c1.Init.OwnAddress1 = 0;
  hi2c1.Init.AddressingMode = I2C_ADDRESSINGMODE_7BIT;
  hi2c1.Init.DualAddressMode = I2C_DUALADDRESS_DISABLE;
  hi2c1.Init.OwnAddress2 = 0;
  hi2c1.Init.GeneralCallMode = I2C_GENERALCALL_DISABLE;
  hi2c1.Init.NoStretchMode = I2C_NOSTRETCH_DISABLE;
  if (HAL_I2C_Init(&hi2c1) != HAL_OK)
  {
    Error_Handler();
  }

}

/* I2C2 init function */
static void MX_I2C2_Init(void)
{

  hi2c2.Instance = I2C2;
  hi2c2.Init.ClockSpeed = 100000;
  hi2c2.Init.DutyCycle = I2C_DUTYCYCLE_2;
  hi2c2.Init.OwnAddress1 = 0;
  hi2c2.Init.AddressingMode = I2C_ADDRESSINGMODE_7BIT;
  hi2c2.Init.DualAddressMode = I2C_DUALADDRESS_DISABLE;
  hi2c2.Init.OwnAddress2 = 0;
  hi2c2.Init.GeneralCallMode = I2C_GENERALCALL_DISABLE;
  hi2c2.Init.NoStretchMode = I2C_NOSTRETCH_DISABLE;
  if (HAL_I2C_Init(&hi2c2) != HAL_OK)
  {
    Error_Handler();
  }

}

/* SPI1 init function */
static void MX_SPI1_Init(void)
{

  hspi1.Instance = SPI1;
  hspi1.Init.Mode = SPI_MODE_MASTER;
  hspi1.Init.Direction = SPI_DIRECTION_2LINES;
  hspi1.Init.DataSize = SPI_DATASIZE_8BIT;
  hspi1.Init.CLKPolarity = SPI_POLARITY_LOW;
  hspi1.Init.CLKPhase = SPI_PHASE_1EDGE;
  hspi1.Init.NSS = SPI_NSS_SOFT;
  hspi1.Init.BaudRatePrescaler = SPI_BAUDRATEPRESCALER_4;
  hspi1.Init.FirstBit = SPI_FIRSTBIT_MSB;
  hspi1.Init.TIMode = SPI_TIMODE_DISABLE;
  hspi1.Init.CRCCalculation = SPI_CRCCALCULATION_DISABLE;
  hspi1.Init.CRCPolynomial = 10;
  if (HAL_SPI_Init(&hspi1) != HAL_OK)
  {
    Error_Handler();
  }

}

/* TIM3 init function */
static void MX_TIM3_Init(void)
{

  TIM_MasterConfigTypeDef sMasterConfig;
  TIM_OC_InitTypeDef sConfigOC;

  htim3.Instance = TIM3;
  htim3.Init.Prescaler = 0;
  htim3.Init.CounterMode = TIM_COUNTERMODE_UP;
  htim3.Init.Period = 0;
  htim3.Init.ClockDivision = TIM_CLOCKDIVISION_DIV1;
  if (HAL_TIM_PWM_Init(&htim3) != HAL_OK)
  {
    Error_Handler();
  }

  sMasterConfig.MasterOutputTrigger = TIM_TRGO_RESET;
  sMasterConfig.MasterSlaveMode = TIM_MASTERSLAVEMODE_DISABLE;
  if (HAL_TIMEx_MasterConfigSynchronization(&htim3, &sMasterConfig) != HAL_OK)
  {
    Error_Handler();
  }

  sConfigOC.OCMode = TIM_OCMODE_PWM1;
  sConfigOC.Pulse = 0;
  sConfigOC.OCPolarity = TIM_OCPOLARITY_HIGH;
  sConfigOC.OCFastMode = TIM_OCFAST_DISABLE;
  if (HAL_TIM_PWM_ConfigChannel(&htim3, &sConfigOC, TIM_CHANNEL_3) != HAL_OK)
  {
    Error_Handler();
  }

  HAL_TIM_MspPostInit(&htim3);

}

/* USART1 init function */
static void MX_USART1_UART_Init(void)
{

  huart1.Instance = USART1;
  huart1.Init.BaudRate = 115200;
  huart1.Init.WordLength = UART_WORDLENGTH_8B;
  huart1.Init.StopBits = UART_STOPBITS_1;
  huart1.Init.Parity = UART_PARITY_NONE;
  huart1.Init.Mode = UART_MODE_TX_RX;
  huart1.Init.HwFlowCtl = UART_HWCONTROL_NONE;
  huart1.Init.OverSampling = UART_OVERSAMPLING_16;
  if (HAL_UART_Init(&huart1) != HAL_OK)
  {
    Error_Handler();
  }

}

/* USART2 init function */
static void MX_USART2_UART_Init(void)
{

  huart2.Instance = USART2;
  huart2.Init.BaudRate = 115200;
  huart2.Init.WordLength = UART_WORDLENGTH_8B;
  huart2.Init.StopBits = UART_STOPBITS_1;
  huart2.Init.Parity = UART_PARITY_NONE;
  huart2.Init.Mode = UART_MODE_TX_RX;
  huart2.Init.HwFlowCtl = UART_HWCONTROL_NONE;
  huart2.Init.OverSampling = UART_OVERSAMPLING_16;
  if (HAL_UART_Init(&huart2) != HAL_OK)
  {
    Error_Handler();
  }

}

/** Configure pins as 
        * Analog 
        * Input 
        * Output
        * EVENT_OUT
        * EXTI
*/
static void MX_GPIO_Init(void)
{

  GPIO_InitTypeDef GPIO_InitStruct;

  /* GPIO Ports Clock Enable */
  __HAL_RCC_GPIOC_CLK_ENABLE();
  __HAL_RCC_GPIOD_CLK_ENABLE();
  __HAL_RCC_GPIOA_CLK_ENABLE();
  __HAL_RCC_GPIOB_CLK_ENABLE();

  /*Configure GPIO pin Output Level */
  HAL_GPIO_WritePin(GPIOC, LED_Pin|CSN_Pin|CE_Pin, GPIO_PIN_RESET);

  /*Configure GPIO pin Output Level */
  HAL_GPIO_WritePin(GPIOB, ON_Pin|MOS_Pin, GPIO_PIN_RESET);

  /*Configure GPIO pins : LED_Pin CSN_Pin CE_Pin */
  GPIO_InitStruct.Pin = LED_Pin|CSN_Pin|CE_Pin;
  GPIO_InitStruct.Mode = GPIO_MODE_OUTPUT_PP;
  GPIO_InitStruct.Speed = GPIO_SPEED_FREQ_LOW;
  HAL_GPIO_Init(GPIOC, &GPIO_InitStruct);

  /*Configure GPIO pins : LEFT_BT_Pin RIGHT_BT_Pin SELECT_Pin UP_Pin 
                           RIGHT_Pin DOWN_Pin BUTTON_F_Pin VIN_Pin 
                           POW_BT_Pin */
  GPIO_InitStruct.Pin = LEFT_BT_Pin|RIGHT_BT_Pin|SELECT_Pin|UP_Pin 
                          |RIGHT_Pin|DOWN_Pin|BUTTON_F_Pin|VIN_Pin 
                          |POW_BT_Pin;
  GPIO_InitStruct.Mode = GPIO_MODE_INPUT;
  GPIO_InitStruct.Pull = GPIO_NOPULL;
  HAL_GPIO_Init(GPIOB, &GPIO_InitStruct);

  /*Configure GPIO pins : LEFT_Pin BUTTON_E_Pin */
  GPIO_InitStruct.Pin = LEFT_Pin|BUTTON_E_Pin;
  GPIO_InitStruct.Mode = GPIO_MODE_INPUT;
  GPIO_InitStruct.Pull = GPIO_NOPULL;
  HAL_GPIO_Init(GPIOA, &GPIO_InitStruct);

  /*Configure GPIO pins : ON_Pin MOS_Pin */
  GPIO_InitStruct.Pin = ON_Pin|MOS_Pin;
  GPIO_InitStruct.Mode = GPIO_MODE_OUTPUT_PP;
  GPIO_InitStruct.Speed = GPIO_SPEED_FREQ_LOW;
  HAL_GPIO_Init(GPIOB, &GPIO_InitStruct);

}

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


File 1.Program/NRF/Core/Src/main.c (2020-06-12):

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

/* Includes ------------------------------------------------------------------*/
#include "main.h"
#include "usb_device.h"
/* USER CODE BEGIN Includes */
#include "my_usbd_customhid.h"
#include "my_usbd_custom_hid_if.h"
#include "my_icons.h"
#include "my_bitmaps.h"
#include "ssd1306.h"
#include "i2c-lcd.h"
#include "string.h"
#include "MY_NRF24.h"
#include "TJ_MPU6050.h"
/* USER CODE END Includes */

/* USER CODE BEGIN PTD */
#define FUNC_ACCEL_GYRO_DATA	128
#define FUNC_JOYSTICK_DATA		129
#define FUNC_ACCEL_GYRO_COMBO	130

#define ADS1115_ADDRESS 0x48

char Program_name[] = {
	'G','a','m','e','p','a','d',
	'S','M','i','c','r','o','m','o','u','s','e',
	'T','e','s','t','1',
	'T','e','s','t','2',
	'T','e','s','t','3',
	'T','e','s','t','4'};
int Program_length[] = {
	7,
	11,
	5,
	5,
	5,
	5,};
int Program_Count = 6;
int Program_Running;

char ADSwrite[6];

char Msg[16];
char Flag[8] = {0,0,0,0,0,0,0,0};
int IsHID = 0;
RawData_Def AccelData, GyroData;

uint64_t PipeAddres = 0x11223344AA;
char RF_RxData[32], RF_TxData[32], BadFunc;

uint8_t dataToSend[20] = {0x00, 0x14, 0x01, 0xEE, 0x0F, 0x00, 0x0F, 0x00, 0xFF, 0xFF, 0x00, 0x00, 0x00, 0x00, 0x00, 0x00, 0x00, 0x00, 0x00, 0x00};
//                        butns|size|     |     | lt  | rt  | lx        | ly        | rx        | ry        | unused
//                                    b10 & b9  & b7  & b8  & dr  & dl  & dd  & du
//

int Serial_Send(uint8_t* Buf, uint32_t *Len){
	CDC_Transmit_FS(Buf, Len);
	return &Len;
}

#define I2C1_SCL_Pin SCL_Pin
#define I2C1_SCL_GPIO_Port SCL_GPIO_Port
#define I2C1_SDA_Pin SDA_Pin
#define I2C1_SDA_GPIO_Port SDA_GPIO_Port

static bool wait_for_gpio_state_timeout(GPIO_TypeDef *port, uint16_t pin, GPIO_PinState state, uint32_t timeout)
 {
    uint32_t Tickstart = HAL_GetTick();
    bool ret = true;
    /* Wait until flag is set */
    for(;(state != HAL_GPIO_ReadPin(port, pin)) && (true == ret);)
    {
        /* Check for the timeout */
        if (timeout != HAL_MAX_DELAY)
        {
            if ((timeout == 0U) || ((HAL_GetTick() - Tickstart) > timeout))
            {
                ret = false;
            }
            else
            {
            }
        }
        asm("nop");
    }
    return ret;
}

static void I2C_ClearBusyFlagErratum(I2C_HandleTypeDef* handle, uint32_t timeout)
{
    GPIO_InitTypeDef GPIO_InitStructure;

    // 1. Clear PE bit.
    CLEAR_BIT(handle->Instance->CR1, I2C_CR1_PE);

    //  2. Configure the SCL and SDA I/Os as General Purpose Output Open-Drain, High level (Write 1 to GPIOx_ODR).
    HAL_I2C_DeInit(handle);

    GPIO_InitStructure.Mode = GPIO_MODE_OUTPUT_OD;
    GPIO_InitStructure.Pull = GPIO_NOPULL;

    GPIO_InitStructure.Pin = I2C1_SCL_Pin;
    HAL_GPIO_Init(GPIOB, &GPIO_InitStructure);

    GPIO_InitStructure.Pin = I2C1_SDA_Pin;
    HAL_GPIO_Init(I2C1_SDA_GPIO_Port, &GPIO_InitStructure);

    // 3. Check SCL and SDA High level in GPIOx_IDR.
    HAL_GPIO_WritePin(I2C1_SDA_GPIO_Port, I2C1_SDA_Pin, GPIO_PIN_SET);
    HAL_GPIO_WritePin(I2C1_SCL_GPIO_Port, I2C1_SCL_Pin, GPIO_PIN_SET);

    wait_for_gpio_state_timeout(I2C1_SCL_GPIO_Port, I2C1_SCL_Pin, GPIO_PIN_SET, timeout);
    wait_for_gpio_state_timeout(I2C1_SDA_GPIO_Port, I2C1_SDA_Pin, GPIO_PIN_SET, timeout);

    // 4. Configure the SDA I/O as General Purpose Output Open-Drain, Low level (Write 0 to GPIOx_ODR).
    HAL_GPIO_WritePin(I2C1_SDA_GPIO_Port, I2C1_SDA_Pin, GPIO_PIN_RESET);

    // 5. Check SDA Low level in GPIOx_IDR.
    wait_for_gpio_state_timeout(I2C1_SDA_GPIO_Port, I2C1_SDA_Pin, GPIO_PIN_RESET, timeout);

    // 6. Configure the SCL I/O as General Purpose Output Open-Drain, Low level (Write 0 to GPIOx_ODR).
    HAL_GPIO_WritePin(I2C1_SCL_GPIO_Port, I2C1_SCL_Pin, GPIO_PIN_RESET);

    // 7. Check SCL Low level in GPIOx_IDR.
    wait_for_gpio_state_timeout(I2C1_SCL_GPIO_Port, I2C1_SCL_Pin, GPIO_PIN_RESET, timeout);

    // 8. Configure the SCL I/O as General Purpose Output Open-Drain, High level (Write 1 to GPIOx_ODR).
    HAL_GPIO_WritePin(I2C1_SCL_GPIO_Port, I2C1_SCL_Pin, GPIO_PIN_SET);

    // 9. Check SCL High level in GPIOx_IDR.
    wait_for_gpio_state_timeout(I2C1_SCL_GPIO_Port, I2C1_SCL_Pin, GPIO_PIN_SET, timeout);

    // 10. Configure the SDA I/O as General Purpose Output Open-Drain , High level (Write 1 to GPIOx_ODR).
    HAL_GPIO_WritePin(I2C1_SDA_GPIO_Port, I2C1_SDA_Pin, GPIO_PIN_SET);

    // 11. Check SDA High level in GPIOx_IDR.
    wait_for_gpio_state_timeout(I2C1_SDA_GPIO_Port, I2C1_SDA_Pin, GPIO_PIN_SET, timeout);

    // 12. Configure the SCL and SDA I/Os as Alternate function Open-Drain.
    GPIO_InitStructure.Mode = GPIO_MODE_AF_OD;
    //MAT//GPIO_InitStructure.Alternate = GPIO_AF1_I2C1;

    GPIO_InitStructure.Pin = I2C1_SCL_Pin;
    HAL_GPIO_Init(I2C1_SCL_GPIO_Port, &GPIO_InitStructure);

    GPIO_InitStructure.Pin = I2C1_SDA_Pin;
    HAL_GPIO_Init(I2C1_SDA_GPIO_Port, &GPIO_InitStructure);

    // 13. Set SWRST bit in I2Cx_CR1 register.
    SET_BIT(handle->Instance->CR1, I2C_CR1_SWRST);
    asm("nop");

    /* 14. Clear SWRST bit in I2Cx_CR1 register. */
    CLEAR_BIT(handle->Instance->CR1, I2C_CR1_SWRST);
    asm("nop");

    /* 15. Enable the I2C peripheral by setting the PE bit in I2Cx_CR1 register */
    SET_BIT(handle->Instance->CR1, I2C_CR1_PE);
    asm("nop");

    // Call initialization function.
    HAL_I2C_Init(handle);
}
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

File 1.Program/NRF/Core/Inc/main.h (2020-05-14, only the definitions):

#define LED_Pin GPIO_PIN_13
#define LED_GPIO_Port GPIOC
#define CSN_Pin GPIO_PIN_14
#define CSN_GPIO_Port GPIOC
#define CE_Pin GPIO_PIN_15
#define CE_GPIO_Port GPIOC
#define HORISONTAL_Pin GPIO_PIN_0
#define HORISONTAL_GPIO_Port GPIOA
#define VERTICAL_Pin GPIO_PIN_1
#define VERTICAL_GPIO_Port GPIOA
#define BT_TX_Pin GPIO_PIN_2
#define BT_TX_GPIO_Port GPIOA
#define BT_RX_Pin GPIO_PIN_3
#define BT_RX_GPIO_Port GPIOA
#define BAT_Pin GPIO_PIN_4
#define BAT_GPIO_Port GPIOA
#define BUZZ_Pin GPIO_PIN_0
#define BUZZ_GPIO_Port GPIOB
#define BT_LD_Pin GPIO_PIN_1
#define BT_LD_GPIO_Port GPIOB
#define BT_LA_Pin GPIO_PIN_2
#define BT_LA_GPIO_Port GPIOB
#define SCL_IMU_Pin GPIO_PIN_10
#define SCL_IMU_GPIO_Port GPIOB
#define SDA_IMU_Pin GPIO_PIN_11
#define SDA_IMU_GPIO_Port GPIOB
#define BT_RS_Pin GPIO_PIN_12
#define BT_RS_GPIO_Port GPIOB
#define BT_RA_Pin GPIO_PIN_13
#define BT_RA_GPIO_Port GPIOB
#define BT_RB_Pin GPIO_PIN_14
#define BT_RB_GPIO_Port GPIOB
#define BT_RC_Pin GPIO_PIN_15
#define BT_RC_GPIO_Port GPIOB
#define BT_RD_Pin GPIO_PIN_8
#define BT_RD_GPIO_Port GPIOA
#define BT_LC_Pin GPIO_PIN_15
#define BT_LC_GPIO_Port GPIOA
#define BT_LB_Pin GPIO_PIN_3
#define BT_LB_GPIO_Port GPIOB
#define VIN_Pin GPIO_PIN_4
#define VIN_GPIO_Port GPIOB
#define ON_Pin GPIO_PIN_5
#define ON_GPIO_Port GPIOB
#define SCL_Pin GPIO_PIN_6
#define SCL_GPIO_Port GPIOB
#define SDA_Pin GPIO_PIN_7
#define SDA_GPIO_Port GPIOB
#define BT_POWER_Pin GPIO_PIN_8
#define BT_POWER_GPIO_Port GPIOB
#define MOS_Pin GPIO_PIN_9
#define MOS_GPIO_Port GPIOB

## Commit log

2020-05-14 Wprowadzono projekt
    [Assembly.0012.iam, Assembly.iam, Joystick.brd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]
2020-06-01 tak samo
    [Obudowa_v1_SHELL_Up.obj]
2020-06-10 Dodano elementy do guzikow
    [Obudowa_v1_SHELL_Down.stl, Obudowa_v1_SHELL_Up.stl, kwadrat.ipt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]

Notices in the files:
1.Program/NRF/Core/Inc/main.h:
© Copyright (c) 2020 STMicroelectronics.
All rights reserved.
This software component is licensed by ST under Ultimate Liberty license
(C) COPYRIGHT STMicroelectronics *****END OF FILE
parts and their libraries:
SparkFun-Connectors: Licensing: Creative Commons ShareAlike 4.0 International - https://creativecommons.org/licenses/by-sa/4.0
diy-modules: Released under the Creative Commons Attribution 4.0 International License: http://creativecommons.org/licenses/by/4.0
